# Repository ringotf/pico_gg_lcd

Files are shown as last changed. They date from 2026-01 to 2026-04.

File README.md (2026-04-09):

# Pico GG LCD

Work-in-progress update to Trirosmos' original RP2040 Game Gear mod.

More details on the [SMSPower Forum Thread](https://www.smspower.org/forums/20164-OpenSourceGameGearScreenReplacementPicoGGLCD)

## Project Status

Alpha. Main features have been proof-of-concepted, and a working prototype built based on the WL355608 branch (with minimal bodge-fixes). 
The firmware supports both Game Gear and Master System mode, but no adjustable scaling options yet.

> [!NOTE]
> **The PCB design is likely to see major changes.** The current build includes unneccessary placeholder components to be removed, amongst other things. The [WL355608-Dev](tree/WL355608_dev) branch will be updated with Beta changes first.

## "Working" Features

- 640x480 "HD" 3.5inch LCD WL-355608
- HDMI video output with stereo audio using [ikjordan PicoDVI branch](https://github.com/ikjordan/picodvi)
- LED Brightness control with Brightness Wheel
- On-Screen menu. For menu items. And other things.
- GG Mode at 4x horizontal, 3x vertical scaling
- SMS mode at 2x scaling
- [Installation Ribbon](#installation-ribbon)
- 3d printable screen holder

### Demo Video Link (Quiet/NoAudio):

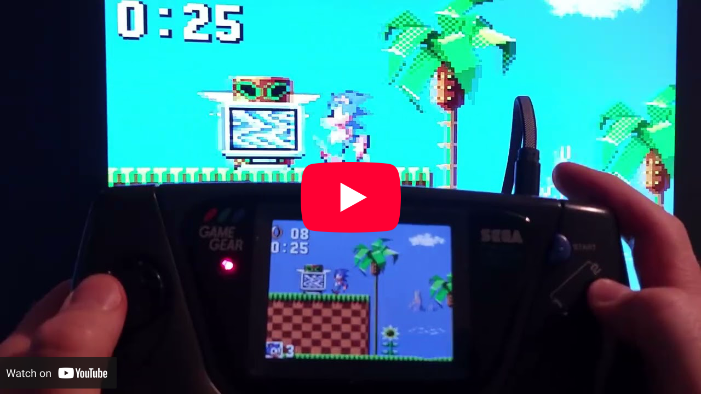
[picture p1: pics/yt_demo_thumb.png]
[](https://www.youtube.com/watch?v=du8Fr7flVrw)

### Another with better audio:

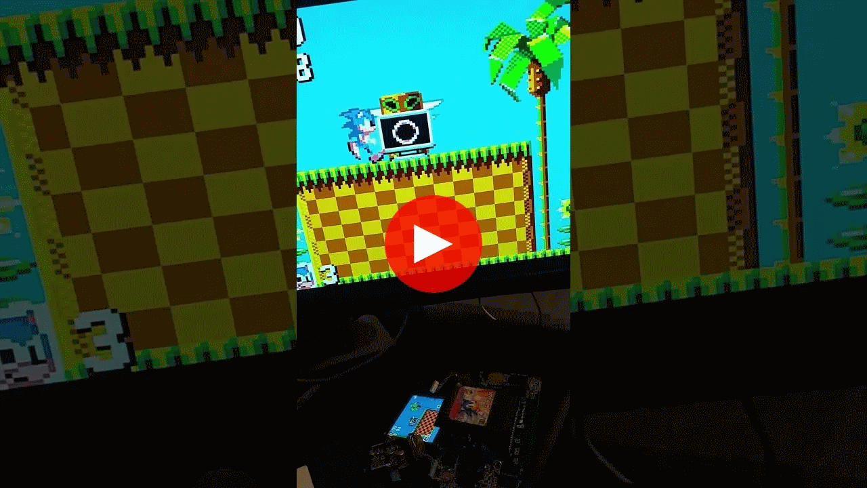
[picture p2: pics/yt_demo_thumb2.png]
[](https://www.youtube.com/watch?v=f37Q6rag2ZQ)

### PCB (Alpha Prototype 4)

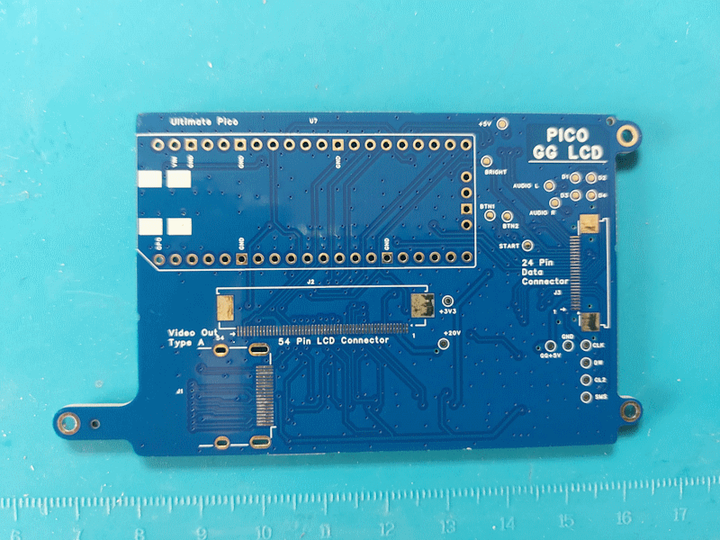
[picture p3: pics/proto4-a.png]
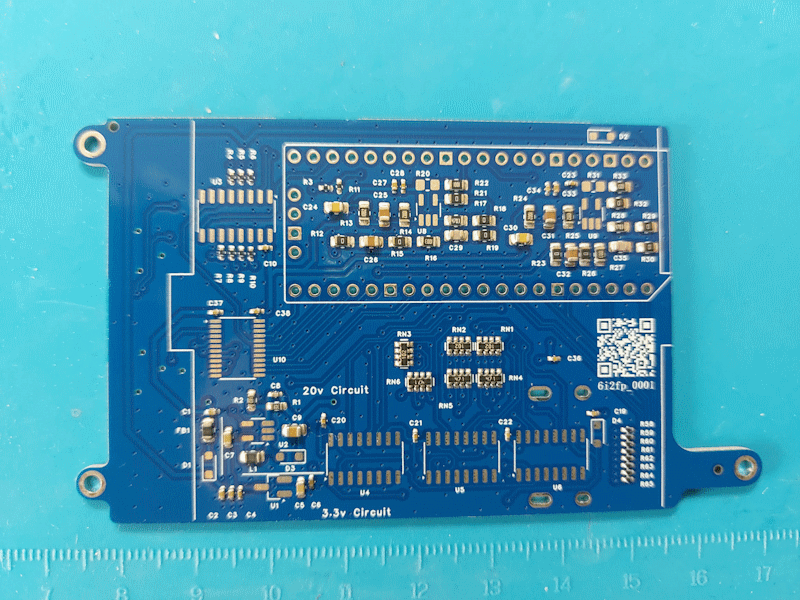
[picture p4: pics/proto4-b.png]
 

## Issues/Upcoming Changes/ToDo

- The LCD connector ribbon is likely to be rotated 180 degrees, will make soldering easier for both LCD and HDMI connectors.
- The op-amps used for audio capture will probably be changed for a dual-op-amp instead of two singles.
- Audio has lots of interference, could be from the LCD mod, could be from the GG.
- The XC6206 3.3v regulator was used to try and eliminate noise from the Pico's onboard regulator interferring with ADC, but might be unneccessary now.
- Remove placeholder components in the audio circuit.
- Corrected LED backlight dimming circuit - currently uses 2 GPIO pins, plus a bodge as shown below.
- The GG Clock pin is no longer needed.
- HDMI Hot-Plug-Detect implemented with the spare Pico GPIO pin.
- Installation Ribbon needs updating to remove the GG Clock pin. 
- Memory. Firmware currently uses 2 framebuffers to help prevent tearing, but with all the other features the Pico is starting to stretch its 264KB RAM... rotating the LCD connector so the LCD is mounted up-right might help allow a single framebuffer and recover some memory for other features.
- The shift registers probably have more performance in them, might be able to work with 2 instead of 3 - might not be worth finding out?

### RP2040 vs RP2350B

Instead of using serial->parallel shift registers to implement the LCD RGB444 input, we could use the extra pins of the Pico2 48-GPIO RP2350B. These are more expensive even after excluding the cost of the 3x 74HC595 shift registers needed for the RP2040, but would simplify the PCB a lot... It was fun to make the project work on an RP2040!

Plus the extra ram of the RP2350 (520KB vs 264KB) will help allow other features to be added to the firmware.

## How It Works

The Game Gear outputs serial RGB444, which is captured using PIO programs and stored in a 16-Bit framebuffer. 
- GG video capture uses 7 GPIO pins: 4 data + 3 control. (*6 without GG Clock now, but anyway)
- PicoDVI output uses 8 GPIO pins.
- LED Backlight brightness control uses 2 GPIO pins.
- LCD requires 3 control signals, Reset, Clock and Data-Enable.

This is 20 pins for capture, HDMI output and LCD control, leaving **10** pins from the 30 GPIO Ultimate Pico.

The LCD expects parallel RGB for 640x480 60Hz. For RGB444 the lcd needs **12** input lines.

To feed the LCD with 12 data inputs, we can use serial-to-parallel shift registers to read data from the Pico serially over a few pins, and send to the LCD over 12 parallel pins.

Although the shift registers have their own timing limits, by using a combination of multiple registers and reusing the same data (scale the image horizontally by clocking the LCD up to 4 times) we can reduce the load on the individual register.

The outputs from the shift registers are interleaved to the LCD to avoid requiring any bit-shifting from the frame buffer.

So the Pico outputs 160 pixels of 12 bit data, with 4 bits per shift register clock to 3 shift registers, and then clocks the LCD 4x for an effective 640 pixels.
Using 5 GPIO pins: 3 MOSI, 1 shift register Latch, 1 shift register clock.

Which leaves a few GPIO pins for audio capture!

### Shift Register Diagram

Hopefully this diagram helps visually explain how the shift registers are wired in:

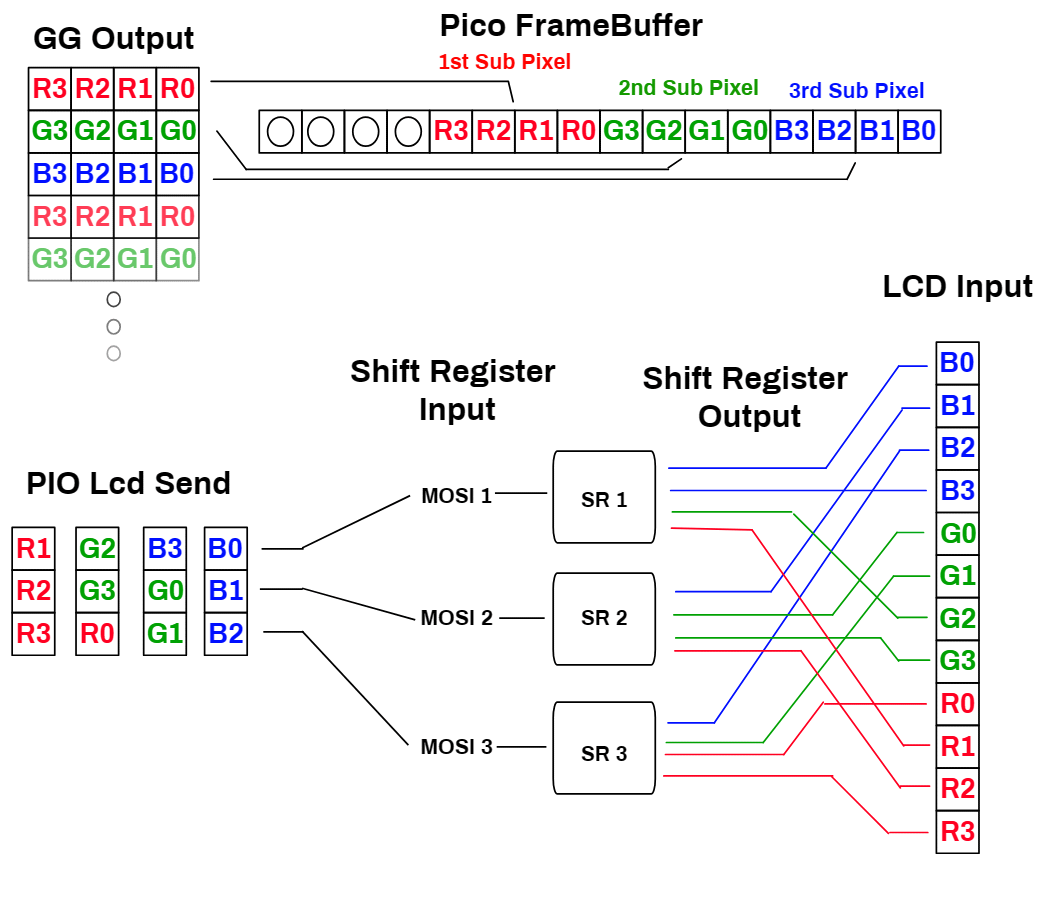
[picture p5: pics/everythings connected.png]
Yes
 

## Build Pics (Including backlight bodge)

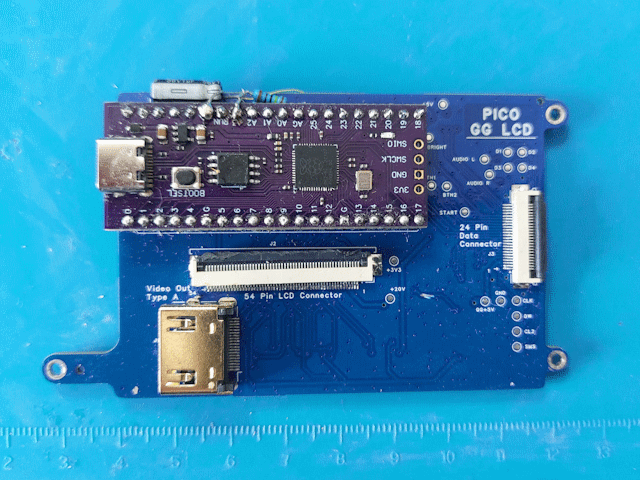
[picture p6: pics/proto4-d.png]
 
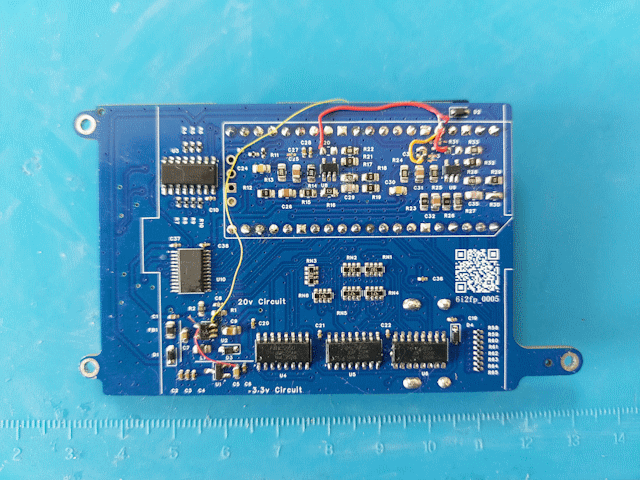
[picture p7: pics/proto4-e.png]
 
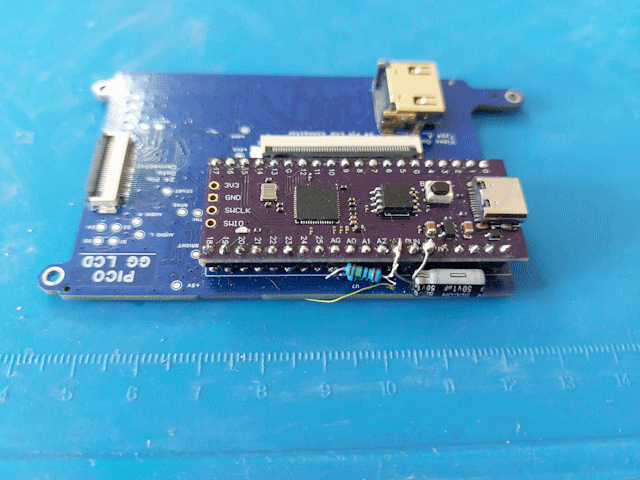
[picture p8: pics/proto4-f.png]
PCB Bodge


### Assembled PCB Test

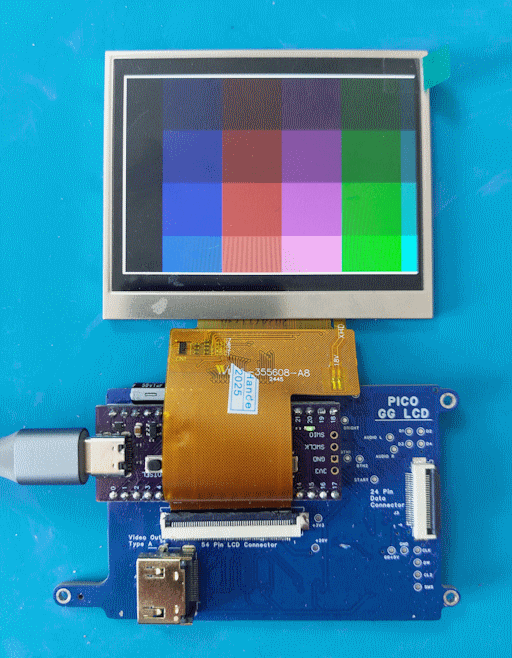
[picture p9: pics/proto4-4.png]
Assembled PCB Test


### Main Board Installed

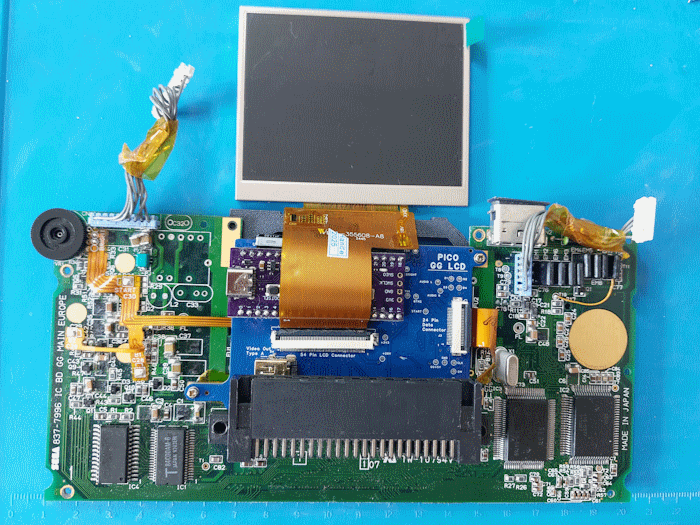
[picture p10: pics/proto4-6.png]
Main Board Installed


### Main Board Testing

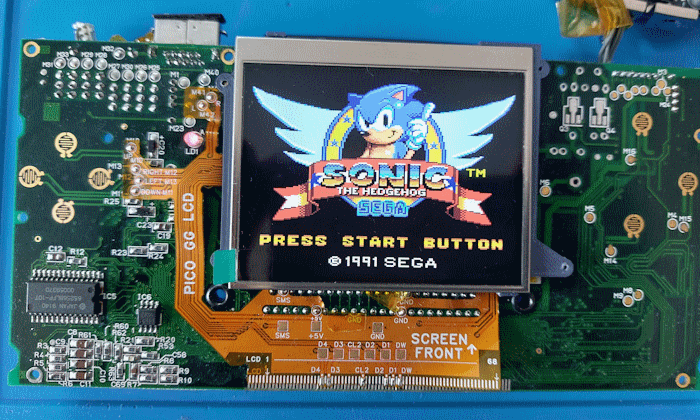
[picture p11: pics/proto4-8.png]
Main Board Testing


### Awaiting Closure

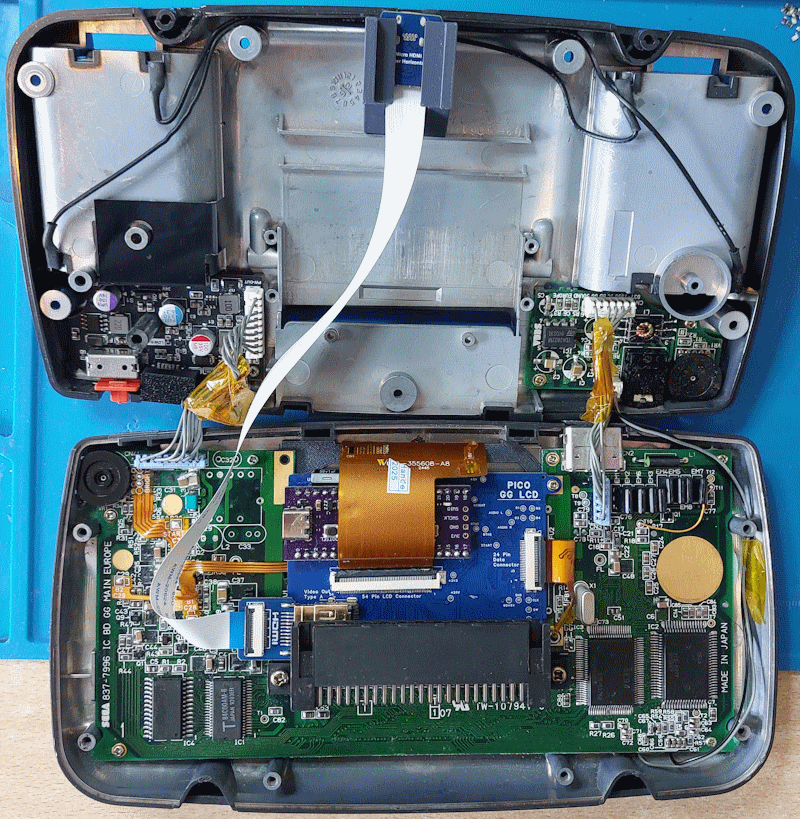
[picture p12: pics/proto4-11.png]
Awaiting Closure


### Completed Build

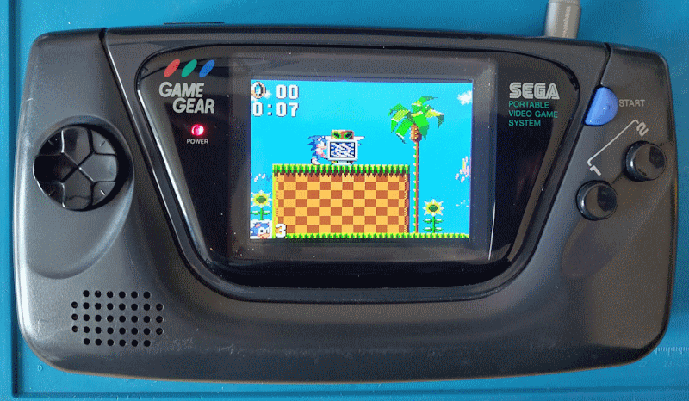
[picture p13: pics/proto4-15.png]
Completed Build


## Installation Ribbon

There is an FPC Installation Ribbon project for easy soldering to the game gear main board. This is designed for the arms to be folded out to reach the various solder points.

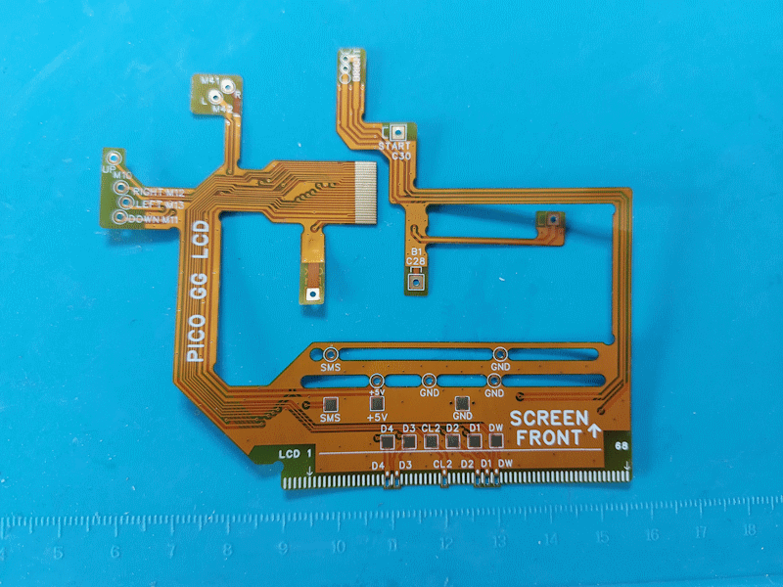
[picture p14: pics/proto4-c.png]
Installation Ribbon


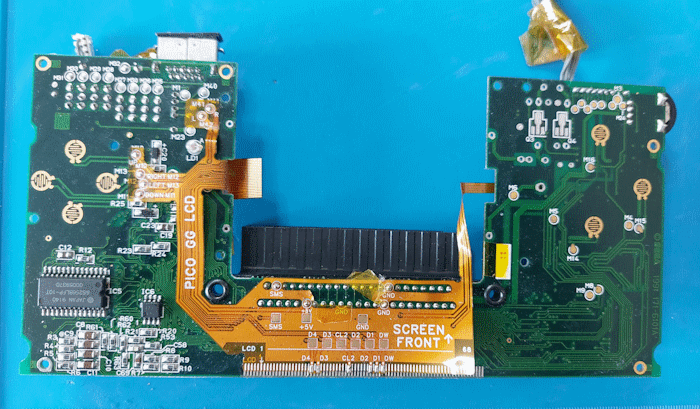
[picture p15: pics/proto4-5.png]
Installed Ribbon Front


## Schematic

Schematic PDF: [hw/GG_LCD_DIY.pdf](hw/GG_LCD_DIY.pdf)

## Gerbers/Bom

Main PCB Gerbers & Bom: [hw\jlcpcb\production_files](hw\jlcpcb\production_files)

Installation Ribbon Gerbers & Bom: [hw\InstallationRibbon\jlcpcb\production_files](hw\InstallationRibbon\jlcpcb\production_files)

Full details in the above files and KiCad project, but here's some of the highlights:

| Component | Description | Quantity |  Example Link(s) | 
| --- | --- | --- | --- |
| Pico GG LCD PCB | Printed Circuit Board | x1 |  |
| WL-355608 | 640x480 3.5" LCD<br />(Also sold as "RG35XX Replacement Screen") | x1 | https://www.aliexpress.com/item/1005005669918579.html <br /> https://www.aliexpress.com/item/1005007035513918.html |
| 30-GPIO Ultimate Pico | Purple RP2040 | x1 | https://www.aliexpress.com/item/1005005594351599.html <br /> https://www.aliexpress.com/item/1005007057526637.html |
| 54-Pin FPC Connector | LCD Ribbon Connector - Flip/Drawer "Bottom" | x1 | https://www.aliexpress.com/item/1005006818638048.html <br /> https://www.aliexpress.com/item/1005008569249941.html |
| 24-Pin FPC Connector | Data Connector - Flip/Drawer "Bottom" | x1 | https://www.aliexpress.com/item/1005006818638048.html <br /> https://www.aliexpress.com/item/1005008569249941.html |
| XC6206P332MR-G | 3.3v Regulator | x1 | https://www.aliexpress.com/item/33025330295.html |
| TPS61040DBVR | 20v Regulator | x1 | https://www.aliexpress.com/item/1005007852981529.html |
| [74HC595D](docs/sn74hc595.pdf) | Serial->Parallel Shift Registers | x3 | https://www.aliexpress.com/item/1005009410525894.html |
| [74HC165D](docs/sn74hc165.pdf) | Parallel->Serial Shift Register | x1 | https://www.aliexpress.com/item/1005009410525894.html |
| [SN74LVC4245APWR](docs/sn74lvc4245a.pdf) | Level-Shifting Transceiver | x1 | https://www.aliexpress.com/item/1005009206069625.html <br /> https://www.aliexpress.com/item/1005011552818805.html |
| [LMV321IDBVR](docs/lmv321.pdf) | Single Op-Amp | x2 | https://www.aliexpress.com/item/1005006127706764.html |
| HDMI Connector |  | x1 Optional | https://www.aliexpress.com/item/1005001412266648.html |
| DIY HDMI Connector | (See note below) | x2 Optional | https://www.aliexpress.com/item/1005004318851140.html <br /> https://www.aliexpress.com/item/1005006437300837.html |
| 20pin 0.5mm FFC | Flat cable for HDMI connectors<br />(Cheap but unshielded) | x1 Optional | https://www.aliexpress.com/item/1005007561337665.html |

Plus inductor, ferrite bead, diodes, capacitors, resistors, resistor network/arrays.

### DIY HDMI Cable Note

> [!WARNING]
> For DIY HDMI Cable, you need to buy **both Male and Female connector ends from the same listing** to ensure compatability with each other. 

Multiple listings included just as examples. If you mix-and-match across listings you might find the connector boards have different pinouts.

The cable requires a Type-A1 Male connector (the standard type) to connect to the PCB, plus a Female receptacle connector to be mounted inside the case, such as the Standard Type-A (often A4), or Micro-HDMI (often D4), or Mini-HDMI (Often C4) plus a 20cm FFC ribbon to join them together. (15cm is probably ok too)

The Micro-HDMI female connector is ideal for the minimising the size of the hole in the case, but still requires an appropriate Micro-HDMI cable or adapter to connect to a TV.

### DIY HDMI Examples 
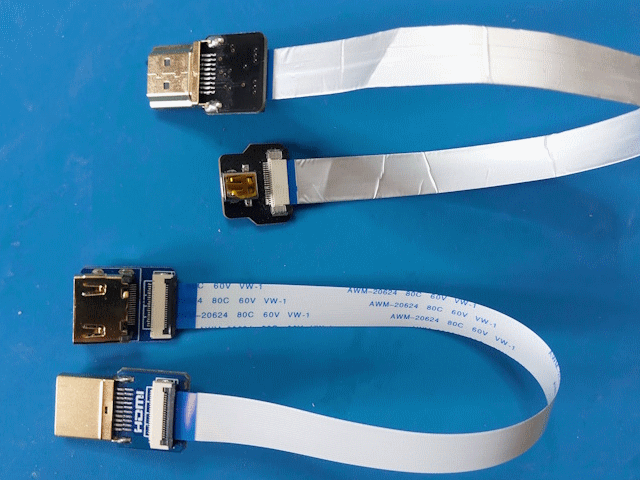
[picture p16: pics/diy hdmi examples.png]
diy hdmi examples


### Micro-HDMI Shell Hole

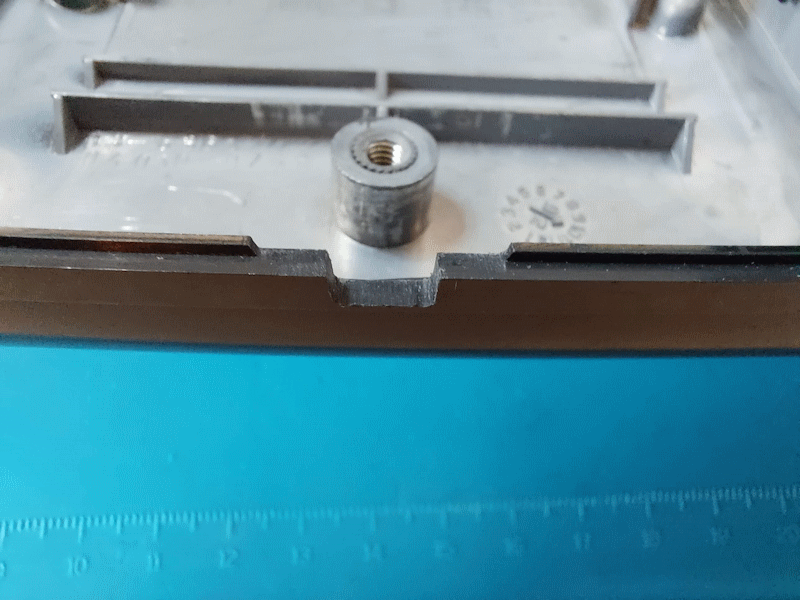
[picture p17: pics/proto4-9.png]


### Micro-HDMI Connector Mounted

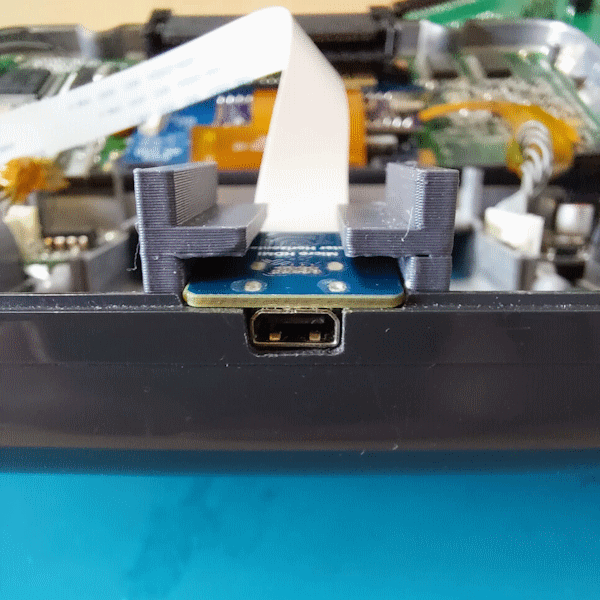
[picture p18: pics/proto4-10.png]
Micro-HDMI Connector Mounted


### Complete Micro-HDMI Install

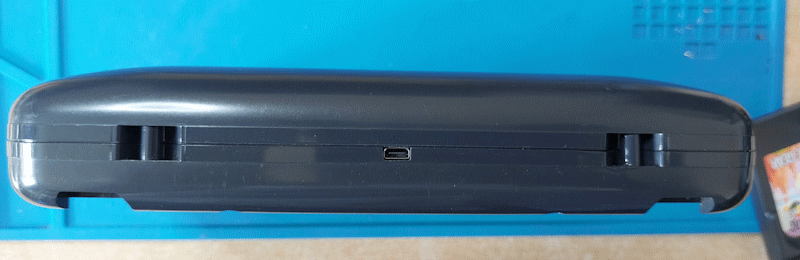
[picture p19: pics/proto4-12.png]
Completed Micro-HDMI Install


### Don't Do This! Careful how the ribbon folds within the case!

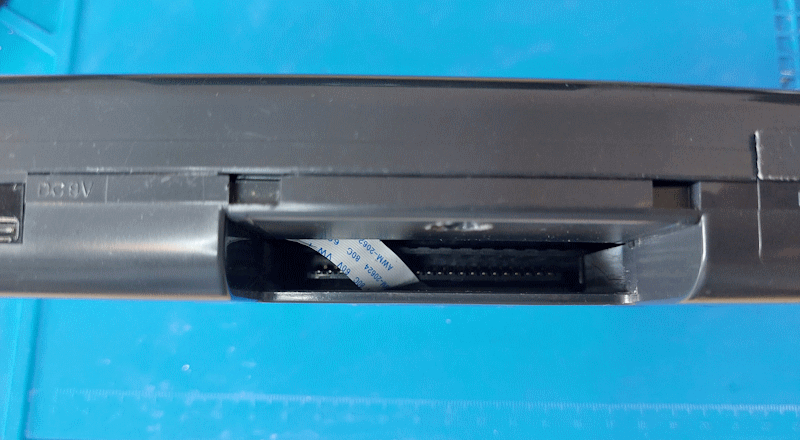
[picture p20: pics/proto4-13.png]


# <br/><br/><br/>
### Original project readme for reference. This branch builds upon the fundamentals below:
<br/><br/>
# Pico GG LCD

install_image

RP2040-based Game Gear screen replacement kit.
Even a cheapo modern LCD has much, much, much better contrast ratio than the OG screen.

## Building the software

Clone this repository and pull all submodules:
```Bash
git clone https://github.com/Trirosmos/pico_gg_lcd
cd pico_gg_lcd
git submodule update --init --recursive
```

Then, run `sw/build.sh`:

```Bash
cd sw
mkdir build
cd build
cmake ../CMakeLists.txt
make
```

This should generate an uf2 file you can upload to the RP2040;

## Building the hardware

Componentes you'll need and their approximate cost:

- Pico GG LCD PCB ($5)
- [PMOD HDMI adapter board](https://aliexpress.com/w/wholesale-pmod%2525252dhdmi.html?spm=a2g0o.detail.search.0) ($4) 
- [54-pin FPC connector adapter board](https://aliexpress.com/item/32827105259.html) ($2)
- [LQ035NC111 LCD module](https://aliexpress.com/w/wholesale-LQ035NC111.html?spm=a2g0o.home.search.0) ($10)
- [RP2040 board that exposes all 30 GPIOs](https://aliexpress.com/item/1005003796653297.html) ($4)
- BS170 or similar NMOSFET ($0.3)
- ~470uH axial THT inductor ($0.2)
- 2x SOD-123 Schottky diode ($0.4)
- 10k 0805 resistor ($0.05)
- 100k 0805 resistor ($0.05)
- 100nF 0805 resistor ($0.05)
- 100uF 0805 resistor ($0.05)
- 22uF 0805 resistor ($0.05)

Total approximate BOM cost: $26

First assemble passive components and transistor, then the RP2040 board and leave the FPC connector to be connected last.
The final board should look something like this, sans the bodge wire:

board_assembly

## How Game Gear video signals work

The Game Gear ASIC generates digital video signals that the LCD drivers in the LCD ribbon use to drive the actual display segments.

In NTSC mode, i.e, when test pad T10 is connected to +5V, the timings of the signals from the ASIC closely resemble what one would expect from a console like the Master System. All screen replacement kits run the Game Gear in this mode, as far as I'm aware. 

The communication protocol used between the ASIC and the LCD drivers in this mode is [well documented](https://www.retrosix.wiki/va0va1-lcd-interface-game-gear) and essentially boils down to:

- 32 MHz pixel clock (same as the main system clock)
- 4 bit data bus carrying one channel of color data at a time
- VSync signal
- HSync signal

## How the RP2040 captures GG video

One of the PIOs is takes alongside three DMA channels with building a live framebuffer in RAM with the image data the GG is sending out.

Three PIO SMs are used in the following manner:

- SM0 detects when a frame starts and triggers an IRQ.
- SM1 detects the IRQ from SM0 and starts detecting HSync pulses. It triggers an IRQ when it does.
- SM2 detects the IRQ from SM1 and proceeds to capture pixel data and push it out to the RX FIFO.

One of the DMA channels then takes the 12bpp pixel data from the PIO RX FIFO and saves it into RAM.

Finally, one of the CPU cores upscales the image and sends it out to the LCD.

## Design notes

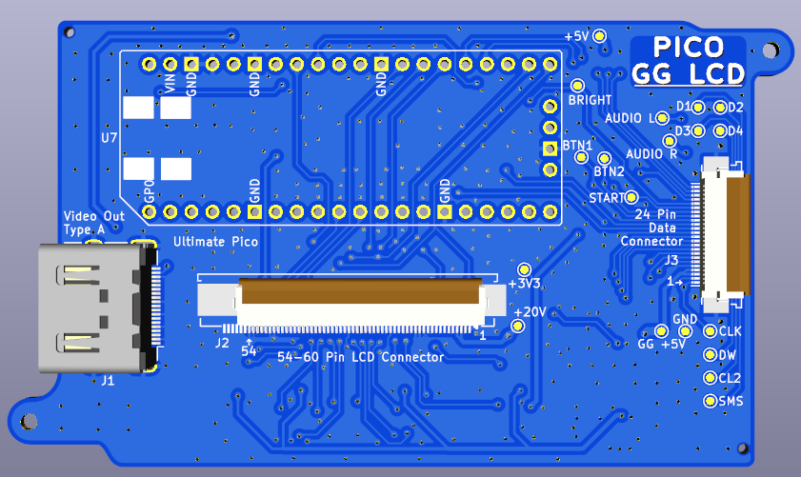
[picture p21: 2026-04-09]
pics/proto3-1.png

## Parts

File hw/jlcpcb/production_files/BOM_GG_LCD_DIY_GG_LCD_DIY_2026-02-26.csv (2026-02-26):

No. | Quantity | Comment | Designator | Footprint | Value | Manufacturer Part | Manufacturer | Supplier Part | Supplier | Name
1 | 5 | 10uF | C1,C2,C3,C27,C33 | gg_lcd:C_0402_1005Metric_Pad0.74x0.62mm_HandSolder | 10uF | CL05A106MQ5NUNC | SAMSUNG(三星) | C15525 | LCSC | 10uF
2 | 12 | 100nF | C4,C10,C19,C20,C21,C22,C23,C28,C34,C36,C37,C38 | gg_lcd:C_0402_1005Metric_Pad0.74x0.62mm_HandSolder | 100nF | CL05B104KO5NNNC | SAMSUNG(三星) | C1525 | LCSC | 100nF
3 | 2 | 22uF | C5,C7 | Capacitor_SMD:C_0603_1608Metric_Pad1.08x0.95mm_HandSolder | 22uF | CL10A226MQ8NRNC | SAMSUNG(三星) | C59461 | LCSC | 22uF
4 | 1 | 1uF | C6 | gg_lcd:C_0402_1005Metric_Pad0.74x0.62mm_HandSolder | 1uF | CL05A105KA5NQNC | SAMSUNG(三星) | C52923 | LCSC | 1uF
5 | 1 | 22pF | C8 | gg_lcd:C_0402_1005Metric_Pad0.74x0.62mm_HandSolder | 22pF | 0402CG220J500NT | FH(风华) | C1555 | LCSC | 22pF
6 | 1 | 22uF | C9 | Capacitor_SMD:C_0805_2012Metric_Pad1.18x1.45mm_HandSolder | 22uF | CL21A226MAQNNNE | SAMSUNG(三星) | C45783 | LCSC | 22uF
7 | 2 | 100nF | C24,C30 | Capacitor_SMD:C_0805_2012Metric_Pad1.18x1.45mm_HandSolder | 100nF | CL21B104KCFNNNE | SAMSUNG(三星) | C28233 | LCSC | 100nF
8 | 4 | 10uF | C25,C26,C31,C32 | Capacitor_SMD:C_0805_2012Metric_Pad1.18x1.45mm_HandSolder | 10uF | CL21A106KAYNNNE | SAMSUNG(三星) | C15850 | LCSC | 10uF
9 | 2 | 22pF | C29,C35 | Capacitor_SMD:C_0805_2012Metric_Pad1.18x1.45mm_HandSolder | 22pF | CL21C220JBANNNC | SAMSUNG(三星) | C1804 | LCSC | 22pF
10 | 3 | B0540WS | D1,D3,D4 | Diode_SMD:D_SOD-323_HandSoldering |  | B0540WS | R+O(宏嘉诚) | C7420326 | LCSC | B0540WS
11 | 1 | B0540WS | D2 | Diode_SMD:D_SOD-323_HandSoldering | B0540WS | B0540WS | R+O(宏嘉诚) | C7420326 | LCSC | B0540WS
12 | 1 | GZ2012D601TF | FB1 | Inductor_SMD:L_0805_2012Metric_Pad1.15x1.40mm_HandSolder | GZ2012D601TF | GZ2012D601TF | Sunlord(顺络) | C1017 | LCSC | GZ2012D601TF
13 | 2 | MountingHole_Pad | H1,H2 | MountingHole:MountingHole_2.2mm_M2_ISO7380_Pad |  |  |  |  |  | MountingHole_Pad
14 | 1 | MountingHole_Pad | H3 | MountingHole:MountingHole_2.2mm_M2_ISO7380_Pad | MountingHole_Pad |  |  |  |  | MountingHole_Pad
15 | 1 | Micro \\"Video Out\\" Type A | J1 | gg_lcd:HDMI_A_Molex_208658-1001_Horizontal | Micro \\"Video Out\\" Type A |  |  |  |  | Micro \\"Video Out\\" Type A
16 | 1 | Conn_01x54 | J2 | gg_lcd:1x54 FPC Connector 0.5mm HandSolder | Conn_01x54 |  |  |  |  | Conn_01x54
17 | 1 | 01x24 Conn | J3 | gg_lcd:Jushuo_AFC07-S24FCA-00_1x24-1MP_P0.50_Horizontal | 01x24 Conn |  |  |  |  | 01x24 Conn
18 | 1 | 10uH | L1 | Inductor_SMD:L_0805_2012Metric_Pad1.15x1.40mm_HandSolder | 10uH | SDFL2012S100KTF | Sunlord(顺络) | C1046 | LCSC | 10uH
19 | 1 | gg_lcd:lcd_template_with_ribbon | LCD1 | gg_lcd:lcd_template_with_ribbon
20 | 1 | MountingHole | MHP1 | MountingHole:ToolingHole_1.152mm |  |  |  |  |  | MountingHole
21 | 1 | MountingHole | MHP2 | MountingHole:ToolingHole_1.152mm | MountingHole |  |  |  |  | MountingHole
22 | 1 | 2MΩ | R1 | Resistor_SMD:R_0603_1608Metric_Pad0.98x0.95mm_HandSolder | 2MΩ | 0603WAF2004T5E | UNI-ROYAL(厚声) | C22976 | LCSC | 2MΩ
23 | 1 | 150kΩ | R2 | Resistor_SMD:R_0603_1608Metric_Pad0.98x0.95mm_HandSolder | 150kΩ | 0603WAF1503T5E | UNI-ROYAL(厚声) | C22807 | LCSC | 150kΩ
24 | 1 | 1kΩ | R3 | gg_lcd:R_0402_1005Metric_Pad0.72x0.64mm_HandSolder | 1kΩ | 0402WGF1001TCE | UNI-ROYAL(厚声) | C11702 | LCSC | 1kΩ
25 | 7 | 100Ω | R4,R5,R6,R7,R8,R9,R10 | gg_lcd:R_0402_1005Metric_Pad0.72x0.64mm_HandSolder | 100Ω | 0402WGF1000TCE | UNI-ROYAL(厚声) | C25076 | LCSC | 100Ω
26 | 1 | 2kΩ | R11 | gg_lcd:R_0402_1005Metric_Pad0.72x0.64mm_HandSolder | 2kΩ | 0402WGF2001TCE | UNI-ROYAL(厚声) | C4109 | LCSC | 2kΩ
27 | 10 | 0Ω | R12,R15,R18,R19,R21,R23,R26,R29,R30,R32 | Resistor_SMD:R_0805_2012Metric_Pad1.20x1.40mm_HandSolder | 0Ω | 0805W8F0000T5E | UNI-ROYAL(厚声) | C17477 | LCSC | 0Ω
28 | 4 | 10kΩ | R13,R14,R24,R25 | Resistor_SMD:R_0805_2012Metric_Pad1.20x1.40mm_HandSolder | 10kΩ | 0805W8F1002T5E | UNI-ROYAL(厚声) | C17414 | LCSC | 10kΩ
29 | 2 | 100kΩ | R16,R27 | Resistor_SMD:R_0805_2012Metric_Pad1.20x1.40mm_HandSolder | 100kΩ | 0805W8F1003T5E | UNI-ROYAL(厚声) | C149504 | LCSC | 100kΩ
30 | 2 | 470kΩ | R17,R28 | Resistor_SMD:R_0805_2012Metric_Pad1.20x1.40mm_HandSolder | 470kΩ | 0805W8F4703T5E | UNI-ROYAL(厚声) | C17709 | LCSC | 470kΩ
31 | 2 | XR | R20,R31 | Resistor_SMD:R_0805_2012Metric_Pad1.20x1.40mm_HandSolder |  |  |  |  |  | XR
32 | 2 | 1kΩ | R22,R33 | Resistor_SMD:R_0805_2012Metric_Pad1.20x1.40mm_HandSolder | 1kΩ | 0805W8F1001T5E | UNI-ROYAL(厚声) | C17513 | LCSC | 1kΩ
33 | 8 | 220Ω | R58,R59,R60,R61,R62,R63,R64,R65 | gg_lcd:R_0402_1005Metric_Pad0.72x0.64mm_HandSolder | 220Ω | 0402WGF2200TCE | UNI-ROYAL(厚声) | C25091 | LCSC | 220Ω
34 | 3 | 1kΩ | RN1,RN2,RN3 | gg_lcd:R_Array_Convex_4x0603 | 1kΩ | 4D03WGJ0102T5E | UNI-ROYAL(厚声) | C20197 | LCSC | 1kΩ
35 | 3 | 470Ω | RN4,RN5,RN6 | gg_lcd:R_Array_Convex_4x0603 | 470Ω | 4D03WGJ0471T5E | UNI-ROYAL(厚声) | C25510 | LCSC | 470Ω
36 | 1 | GG+5V | T1 | gg_lcd:TestPoint_Pad_D1.0mm |  |  |  |  |  | GG+5V
37 | 1 | GND | T2 | gg_lcd:TestPoint_Pad_D1.0mm |  |  |  |  |  | GND
38 | 1 | BRIGHT | T3 | gg_lcd:TestPoint_Pad_D1.0mm |  |  |  |  |  | BRIGHT
39 | 1 | START | T4 | gg_lcd:TestPoint_Pad_D1.0mm |  |  |  |  |  | START
40 | 1 | BTN2 | T5 | gg_lcd:TestPoint_Pad_D1.0mm |  |  |  |  |  | BTN2
41 | 1 | BTN1 | T6 | gg_lcd:TestPoint_Pad_D1.0mm |  |  |  |  |  | BTN1
42 | 1 | AUDIO L | T11 | gg_lcd:TestPoint_Pad_D1.0mm |  |  |  |  |  | AUDIO L
43 | 1 | AUDIO R | T12 | gg_lcd:TestPoint_Pad_D1.0mm |  |  |  |  |  | AUDIO R
44 | 1 | CLK | T13 | gg_lcd:TestPoint_Pad_D1.0mm |  |  |  |  |  | CLK
45 | 1 | SMS | T14 | gg_lcd:TestPoint_Pad_D1.0mm | SMS |  |  |  |  | SMS
46 | 1 | DW | T15 | gg_lcd:TestPoint_Pad_D1.0mm |  |  |  |  |  | DW
47 | 1 | CL2 | T16 | gg_lcd:TestPoint_Pad_D1.0mm |  |  |  |  |  | CL2
48 | 1 | D4 | T17 | gg_lcd:TestPoint_Pad_D1.0mm |  |  |  |  |  | D4
49 | 1 | D3 | T18 | gg_lcd:TestPoint_Pad_D1.0mm |  |  |  |  |  | D3
50 | 1 | D2 | T19 | gg_lcd:TestPoint_Pad_D1.0mm |  |  |  |  |  | D2
51 | 1 | D1 | T20 | gg_lcd:TestPoint_Pad_D1.0mm |  |  |  |  |  | D1
52 | 1 | +3V3 | TP15 | gg_lcd:TestPoint_Pad_D1.0mm |  |  |  |  |  | +3V3
53 | 1 | +20V | TP16 | gg_lcd:TestPoint_Pad_D1.0mm |  |  |  |  |  | +20V
54 | 1 | +5V | TP17 | gg_lcd:TestPoint_Pad_D1.0mm |  |  |  |  |  | +5V
55 | 1 | XC6206P332MR-G | U1 | Package_TO_SOT_SMD:SOT-23_Handsoldering | XC6206P332MR-G | XC6206P332MR-G | TOREX(特瑞仕) | C5446 | LCSC | XC6206P332MR-G
56 | 1 | TPS61040DBVR | U2 | Package_TO_SOT_SMD:SOT-23-5_HandSoldering |  | TPS61040DBVR | TI(德州仪器) | C7722 | LCSC | TPS61040DBVR
57 | 1 | 74HC165D,653 | U3 | Package_SO:SO-16_3.9x9.9mm_P1.27mm |  | 74HC165D,653 | Nexperia(安世) | C5613 | LCSC | 74HC165D,653
58 | 2 | 74HC595D,118 | U4,U5 | Package_SO:SO-16_3.9x9.9mm_P1.27mm |  | 74HC595D,118 | Nexperia(安世) | C5947 | LCSC | 74HC595D,118
59 | 1 | 74HC595D,118 | U6 | Package_SO:SO-16_3.9x9.9mm_P1.27mm | 74HC595 | 74HC595D,118 | Nexperia(安世) | C5947 | LCSC | 74HC595D,118
60 | 1 | Utimate Pico | U7 | gg_lcd:RPi_Pico_SMD_TH_NoPads | Utimate Pico |  |  |  |  | Utimate Pico
61 | 1 | LMV321IDBVR | U8 | Package_TO_SOT_SMD:SOT-23-5_HandSoldering | TPS61040DBV | LMV321IDBVR | TI(德州仪器) | C7972 | LCSC | LMV321IDBVR
62 | 1 | LMV321IDBVR | U9 | Package_TO_SOT_SMD:SOT-23-5_HandSoldering |  | LMV321IDBVR | TI(德州仪器) | C7972 | LCSC | LMV321IDBVR
63 | 1 | SN74LVC4245APWR | U10 | gg_lcd:TSSOP-24_4.4x7.8mm_P0.65mm | SN74LVC4245APWR | SN74LVC4245APWR | TI(德州仪器) | C7859 | LCSC | SN74LVC4245APWR

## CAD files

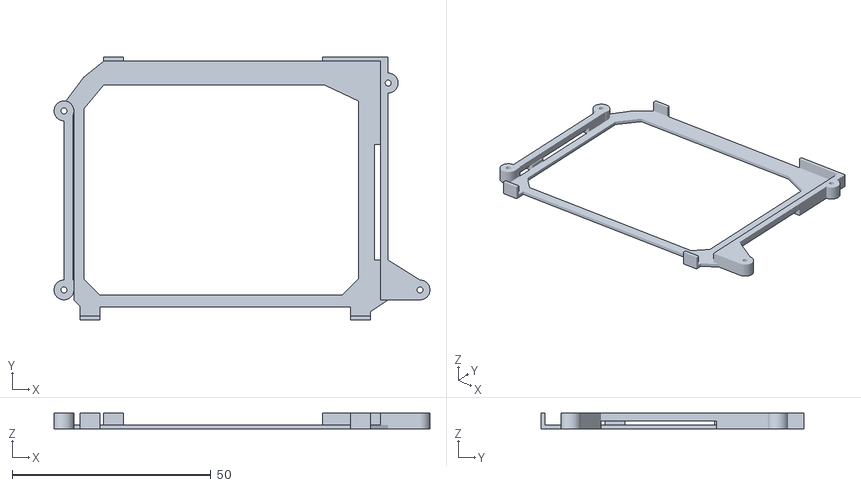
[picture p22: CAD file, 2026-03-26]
3dprints/PICO GG LCD FRAME 2.stl
94.5 x 66.0 x 4.00

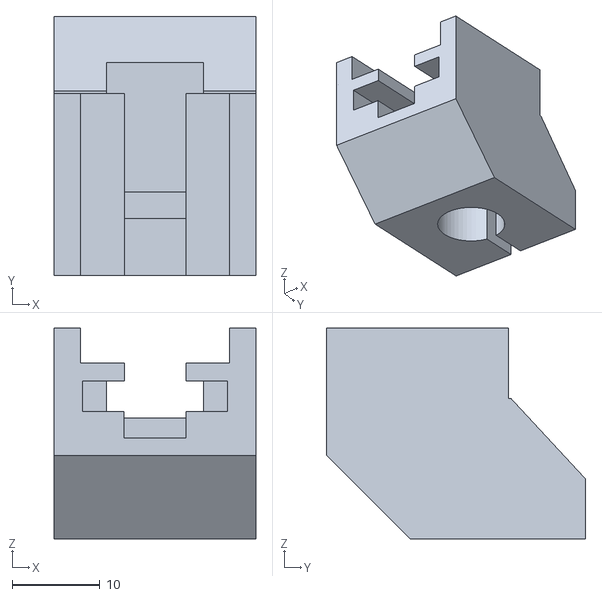
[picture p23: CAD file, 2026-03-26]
3dprints/PICO GG MICRO NOT HDMI UPSIDEDOWN 2.stl
23.0 x 29.5 x 24.0

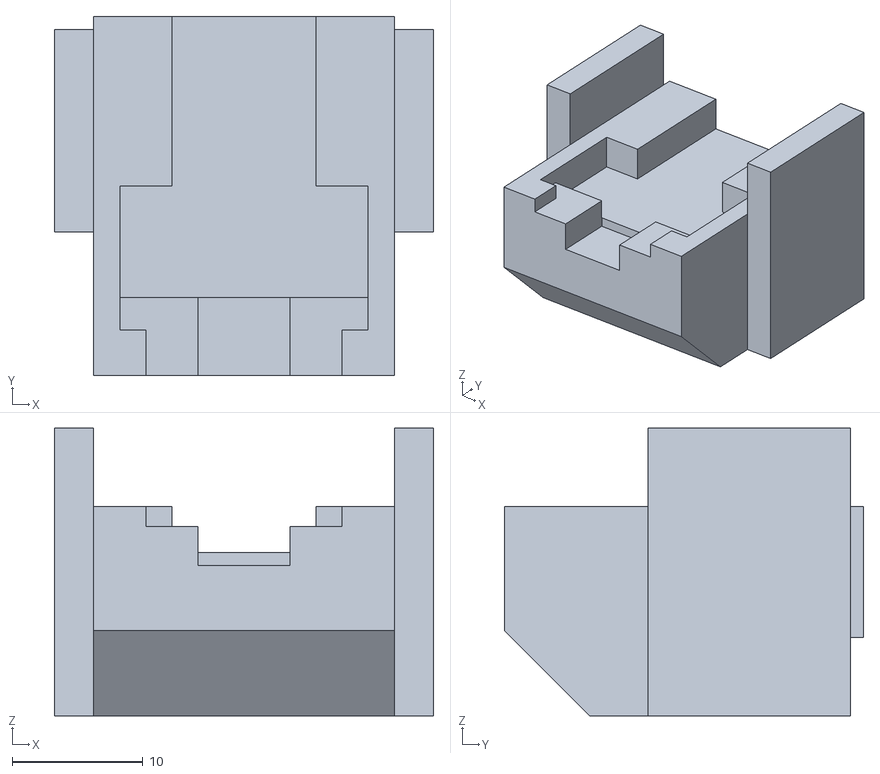
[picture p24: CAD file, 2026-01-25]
3dprints/PICO GG MICRO NOT HDMI UPSIDEDOWN.stl
29.0 x 27.5 x 22.0

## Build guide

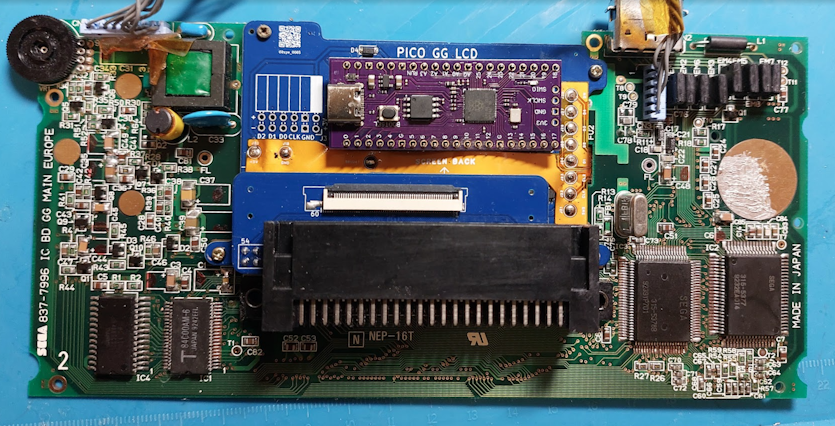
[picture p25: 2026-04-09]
pics/build1d.png

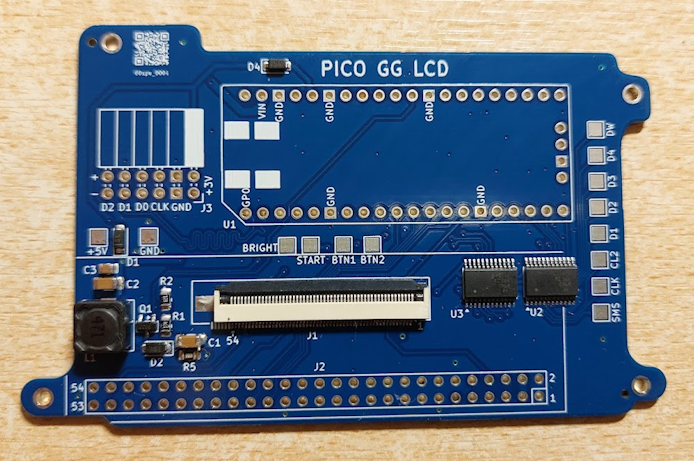
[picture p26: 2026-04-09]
pics/build1e.png

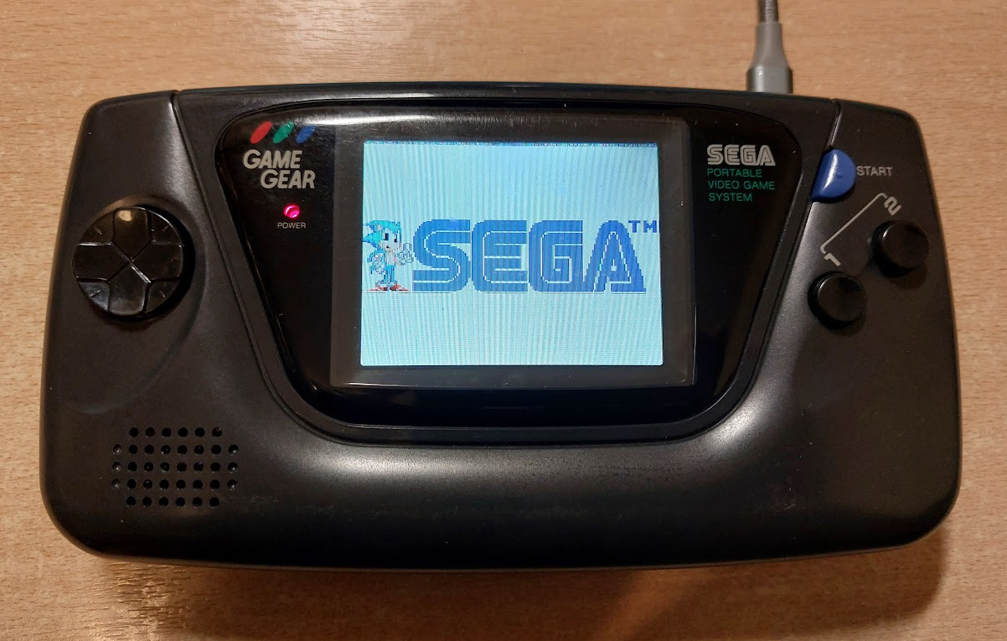
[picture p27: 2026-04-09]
pics/build1a.png

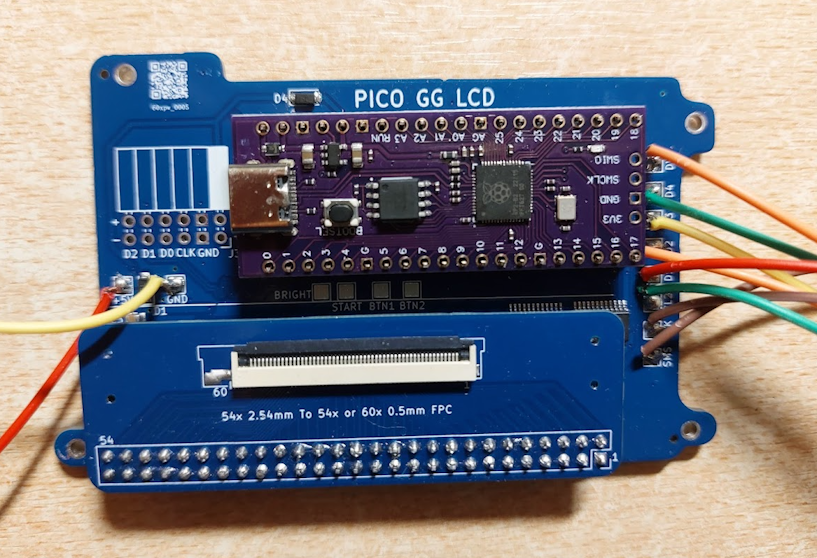
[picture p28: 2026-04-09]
pics/build1f.png

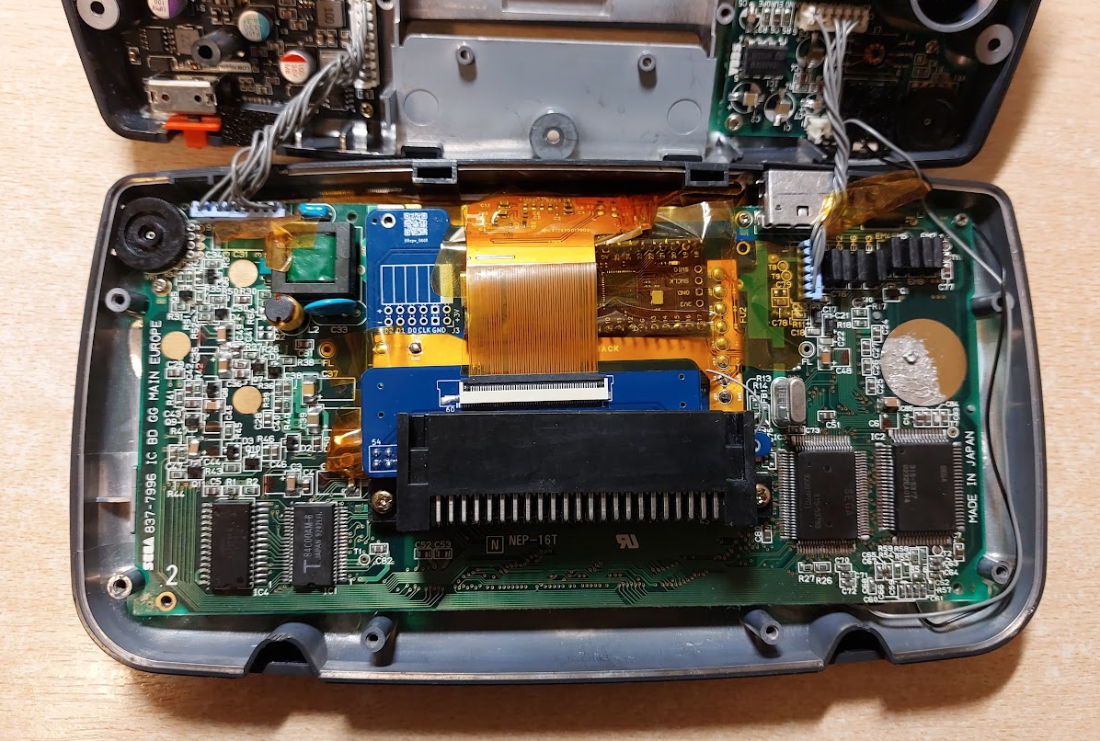
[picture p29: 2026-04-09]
pics/build1b.png

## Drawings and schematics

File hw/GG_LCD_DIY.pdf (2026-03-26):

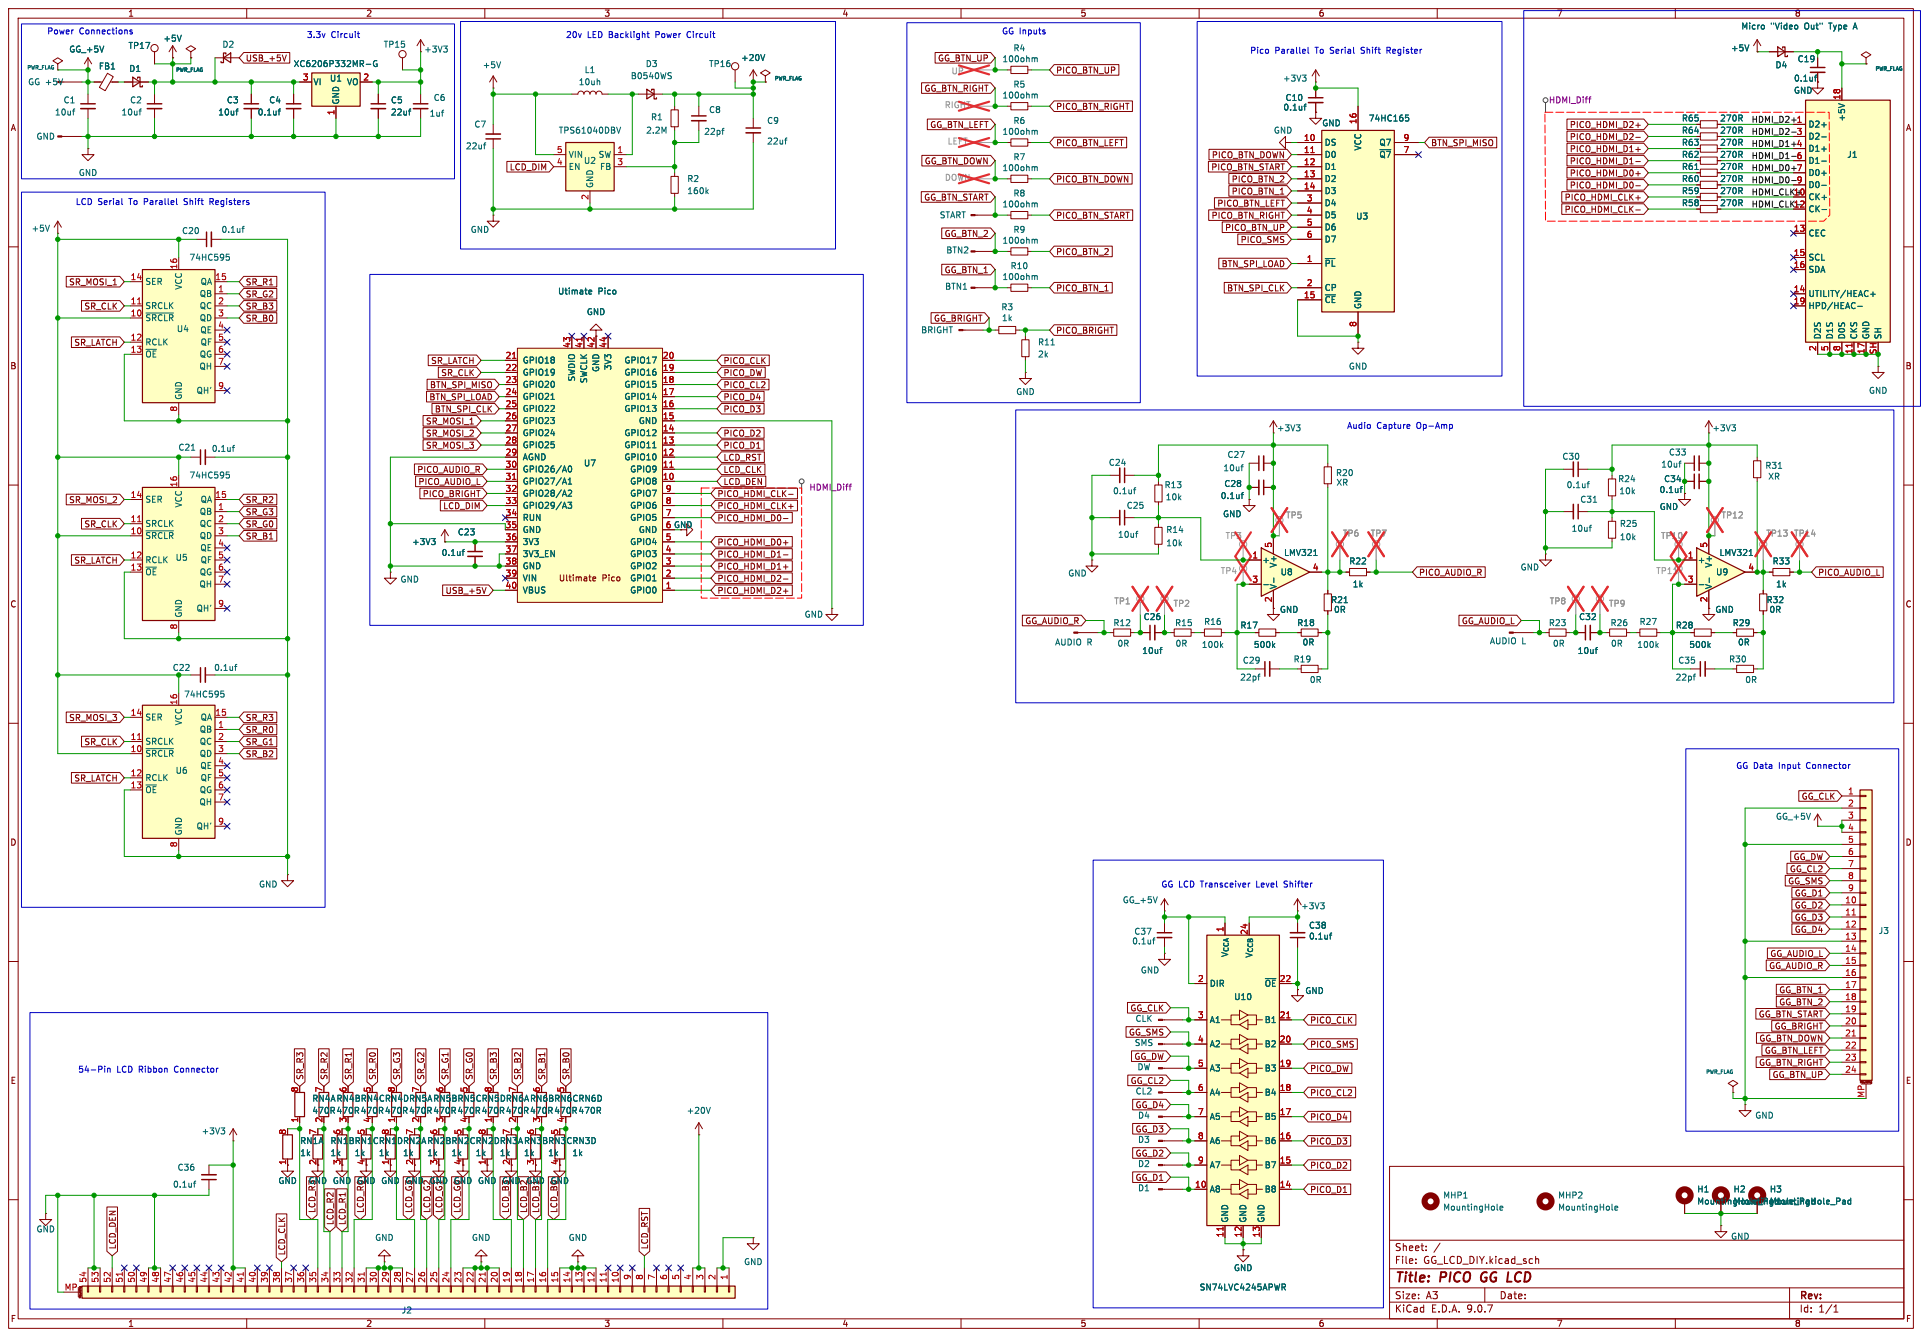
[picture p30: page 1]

J1 Micro "Video Out" Type A

8 CKS 11 GND 17 SH SH

GG Data Input Connector

File: GG_LCD_DIY.kicad_sch Sheet: /
Id: 1/1 Title: PICO GG LCD

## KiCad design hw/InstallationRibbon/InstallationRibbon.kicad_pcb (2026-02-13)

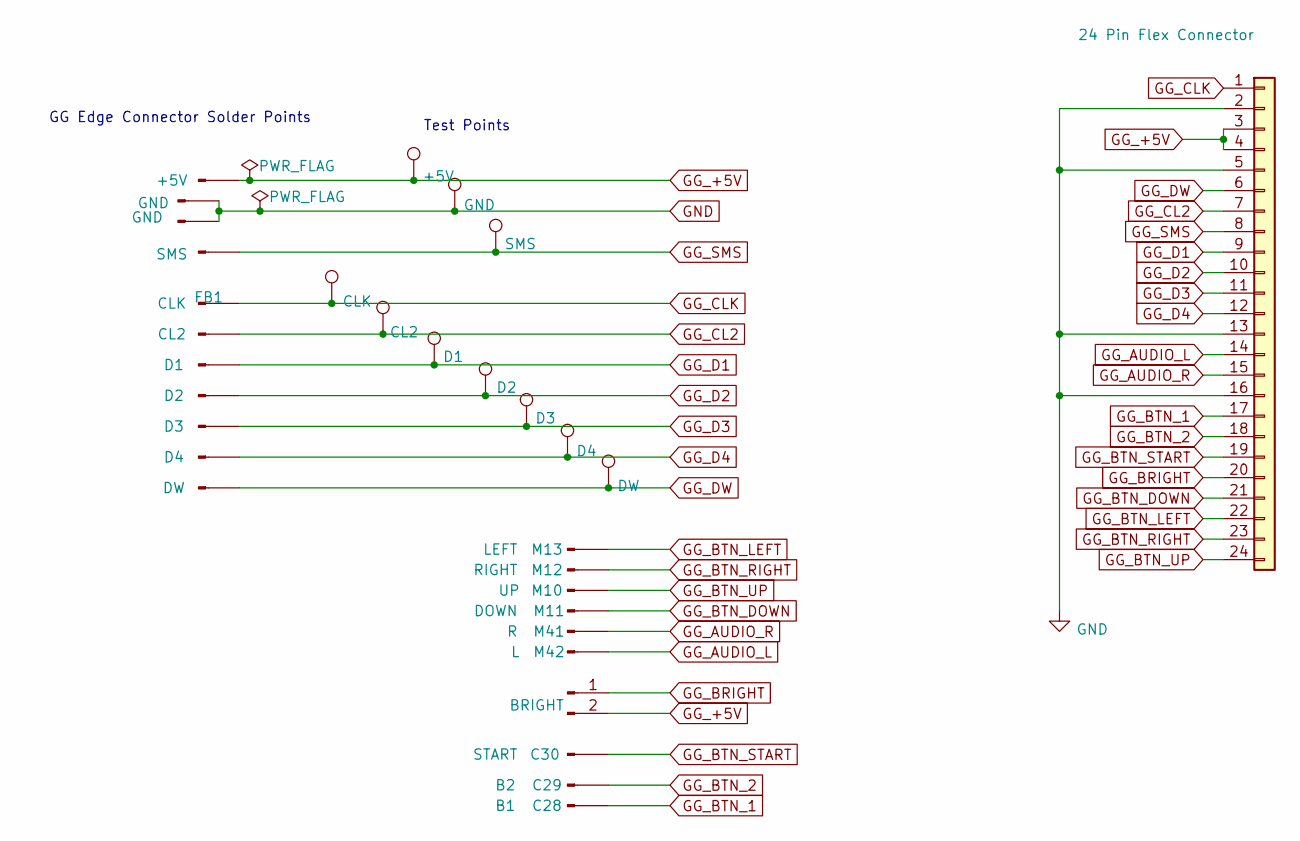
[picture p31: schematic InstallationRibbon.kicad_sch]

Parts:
J1: +5V; TestPoint_THTPad_D2.5mm_Drill1.2mm
J3: CLK; TestPoint_THTPad_D2.5x2.5mm_Drill1.2mm
J4: SMS; TestPoint_THTPad_D2.5mm_Drill1.2mm
J5: DW; SolderWirePad_1x01_EdgeWithHole_1x2mm
J6: CL2; SolderWirePad_1x01_EdgeWithHole_1x2mm
J7: D1; SolderWirePad_1x01_EdgeWithHole_1x2mm
J8: D2; SolderWirePad_1x01_EdgeWithHole_1x2mm
J9: D3; SolderWirePad_1x01_EdgeWithHole_1x2mm
J10: D4; SolderWirePad_1x01_EdgeWithHole_1x2mm
J12: LEFT; TestPoint_THTPad_D2.5mm_Drill1.2mm
J13: RIGHT; TestPoint_THTPad_D2.5mm_Drill1.2mm
J14: UP; TestPoint_THTPad_D2.5mm_Drill1.2mm
J15, J16: GND; TestPoint_THTPad_D2.5mm_Drill1.2mm
J17: 24 Pin Flex Connector; Flex Connector 0.5mm 01x24Pin
J18: DOWN; TestPoint_THTPad_D2.5mm_Drill1.2mm
J19: R; TestPoint_THTPad_D2.5mm_Drill1.2mm
J20: L; TestPoint_THTPad_D2.5mm_Drill1.2mm
J21: START; TestPoint_THTPad_D2.5x2.5mm_Drill1.2mm
J22: B2; TestPoint_THTPad_D2.5x2.5mm_Drill1.2mm
J23: B1; TestPoint_THTPad_D2.5x2.5mm_Drill1.2mm
J25: BRIGHT; TestPoint_2Pads_Pitch2.00mm_Drill1.0mm_OneSide
TP1: +5V; TestPoint_Pad_2.0x2.0mm
TP2: GND; TestPoint_Pad_2.0x2.0mm
TP3: CLK; TestPoint_Pad_2.0x2.0mm
TP4: SMS; TestPoint_Pad_2.0x2.0mm
TP5: DW; TestPoint_Pad_2.0x2.0mm
TP6: CL2; TestPoint_Pad_2.0x2.0mm
TP7: D4; TestPoint_Pad_2.0x2.0mm
TP8: D3; TestPoint_Pad_2.0x2.0mm
TP9: D2; TestPoint_Pad_2.0x2.0mm
TP10: D1; TestPoint_Pad_2.0x2.0mm

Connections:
GG_+5V: J1.1, J17.3, J17.4, J25.2, TP1.1
GG_AUDIO_L: J17.14, J20.1
GG_AUDIO_R: J17.15, J19.1
GG_BRIGHT: J17.20, J25.1
GG_BTN_1: J17.17, J23.1
GG_BTN_2: J17.18, J22.1
GG_BTN_DOWN: J17.21, J18.1
GG_BTN_LEFT: J12.1, J17.22
GG_BTN_RIGHT: J13.1, J17.23
GG_BTN_START: J17.19, J21.1
GG_BTN_UP: J14.1, J17.24
GG_CL2: J6.1, J17.7, TP6.1
GG_CLK: J3.1, J17.1, TP3.1
GG_D1: J7.1, J17.9, TP10.1
GG_D2: J8.1, J17.10, TP9.1
GG_D3: J9.1, J17.11, TP8.1
GG_D4: J10.1, J17.12, TP7.1
GG_DW: J5.1, J17.6, TP5.1
GG_SMS: J4.1, J17.8, TP4.1
GND: J15.1, J16.1, J17.2, J17.5, J17.13, J17.16, TP2.1

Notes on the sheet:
Test Points
GG Edge Connector Solder Points

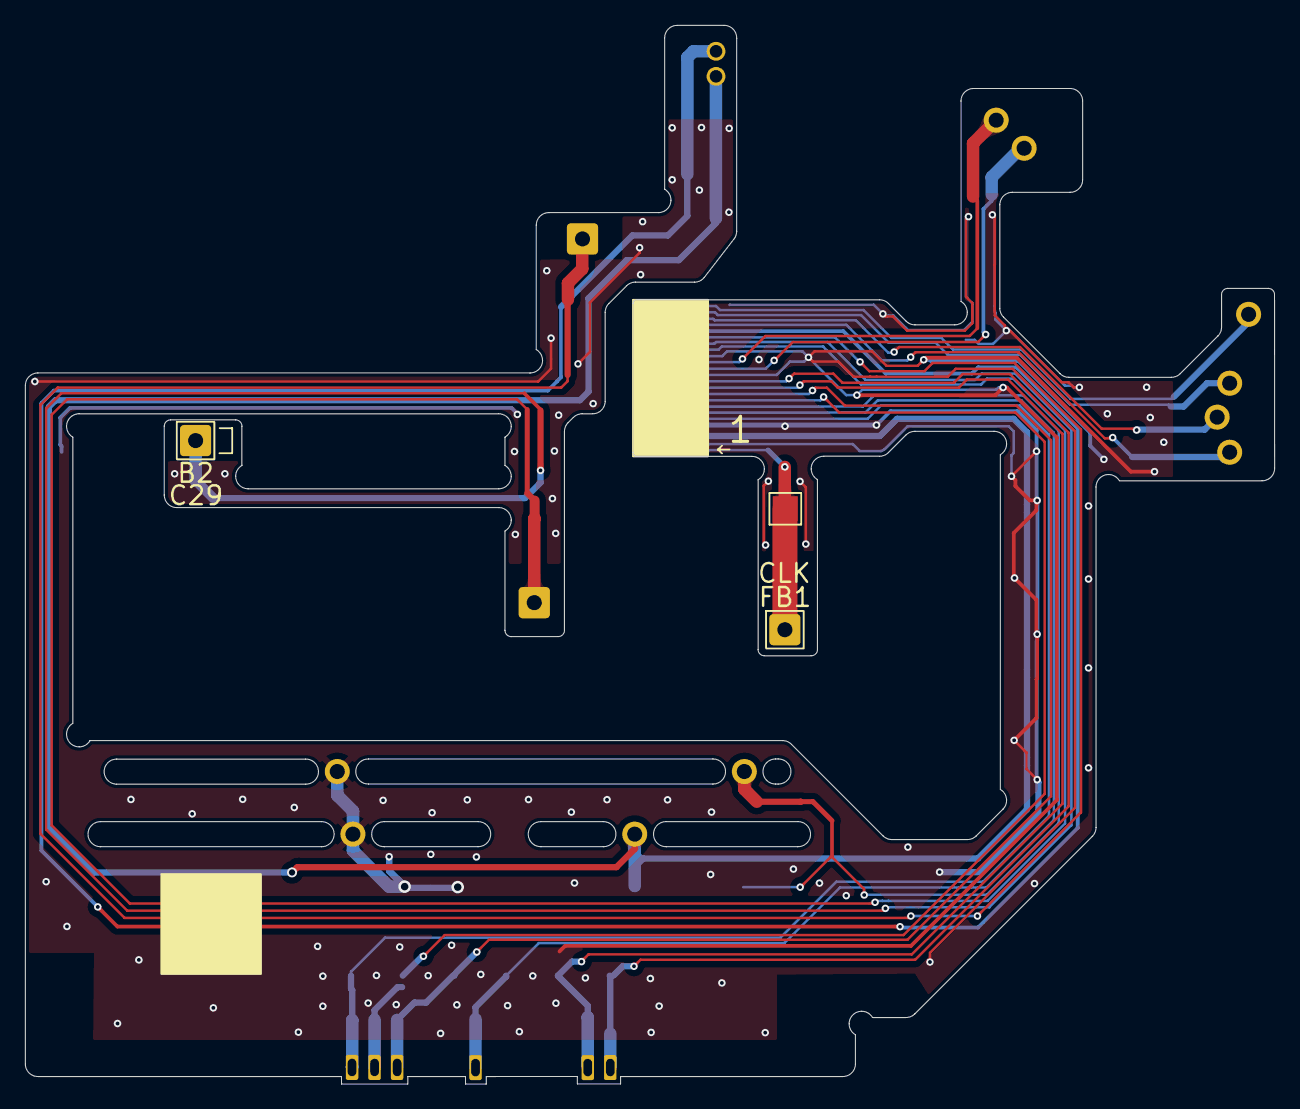
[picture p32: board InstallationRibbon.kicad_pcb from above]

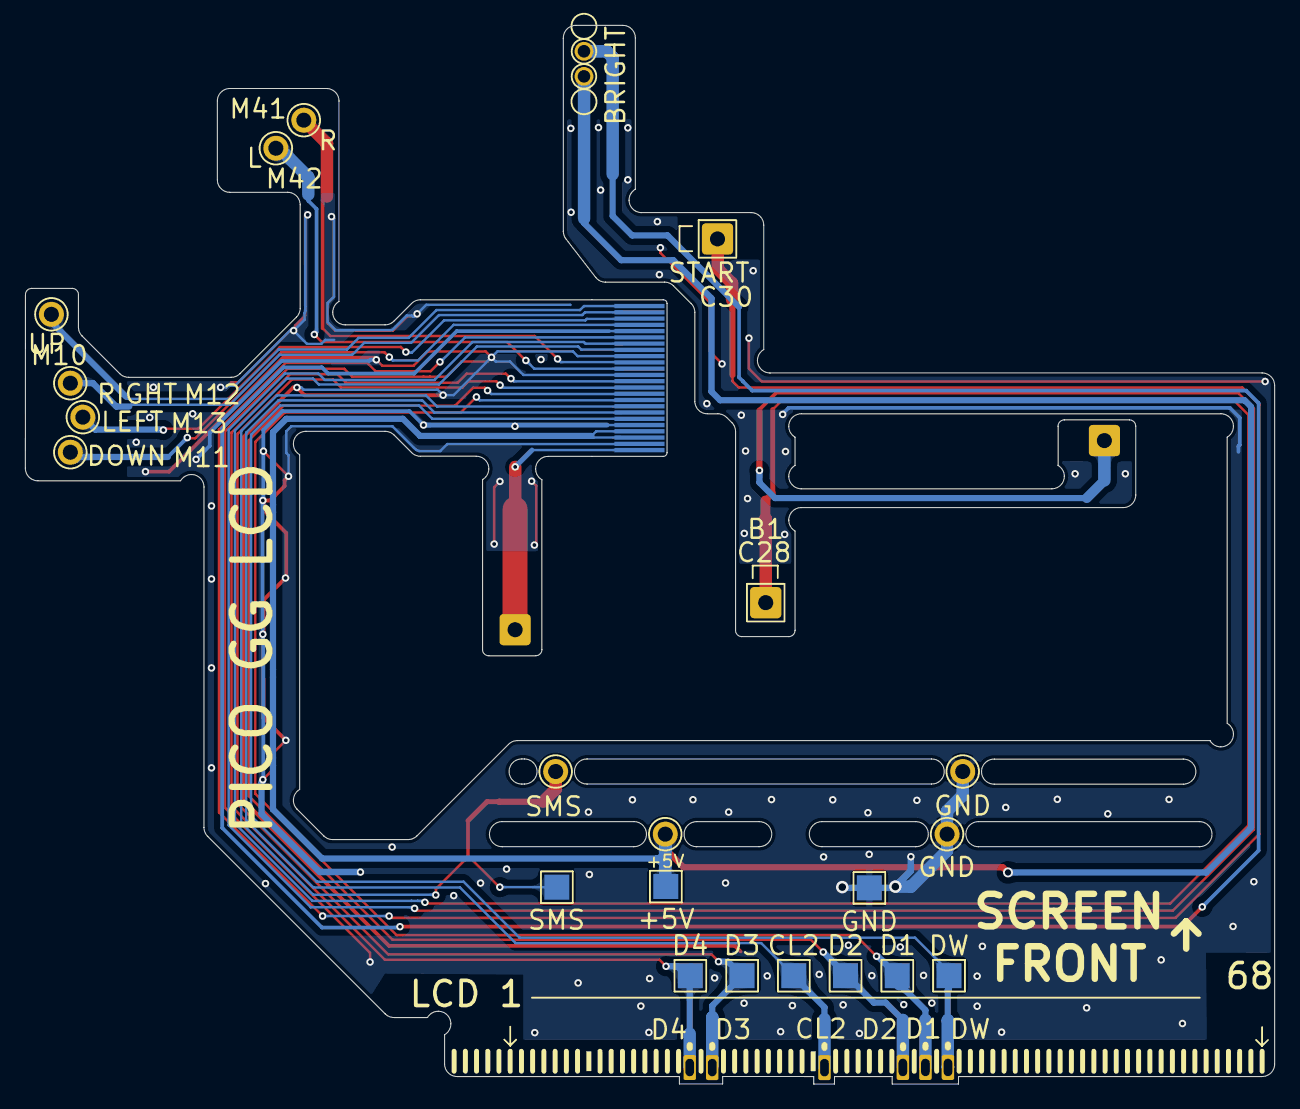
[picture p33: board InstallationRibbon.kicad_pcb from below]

Board: 2 copper layers, 99.7 x 84.5 mm, 32 parts (29 on the bottom side), 20 nets.

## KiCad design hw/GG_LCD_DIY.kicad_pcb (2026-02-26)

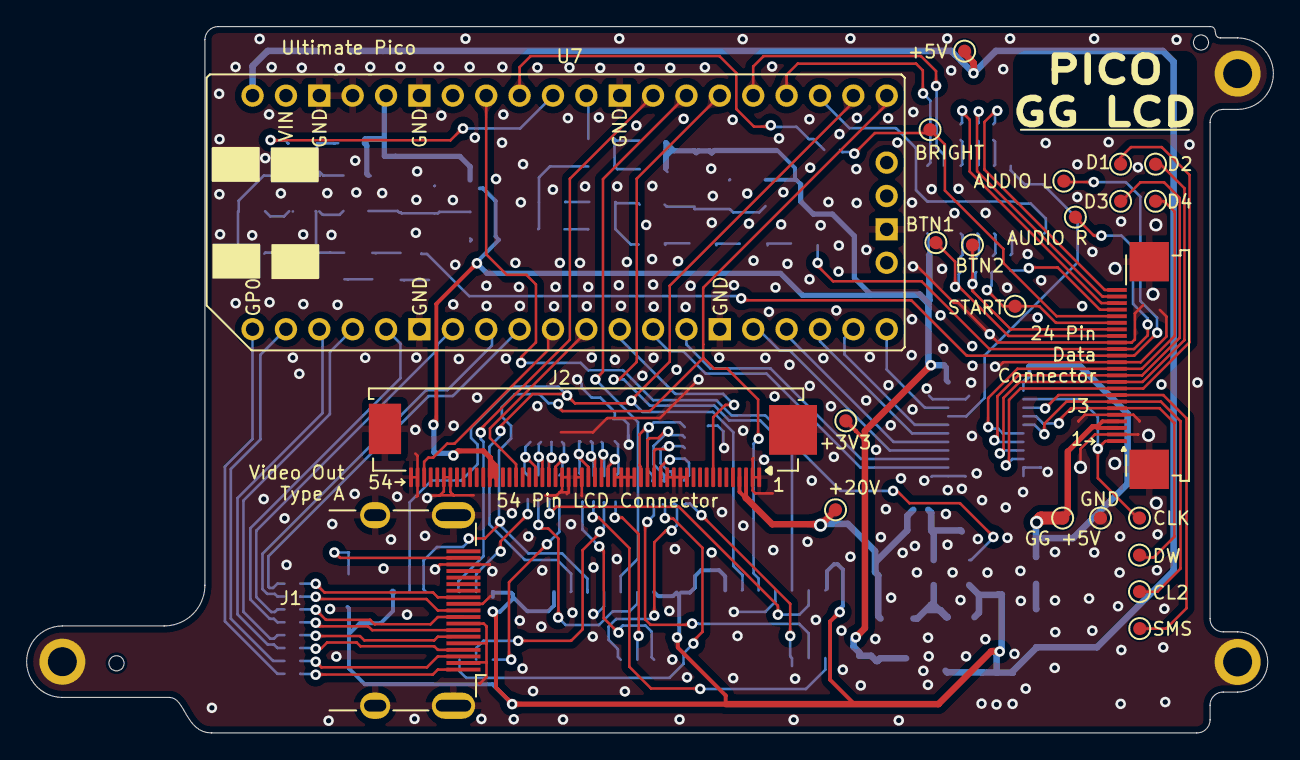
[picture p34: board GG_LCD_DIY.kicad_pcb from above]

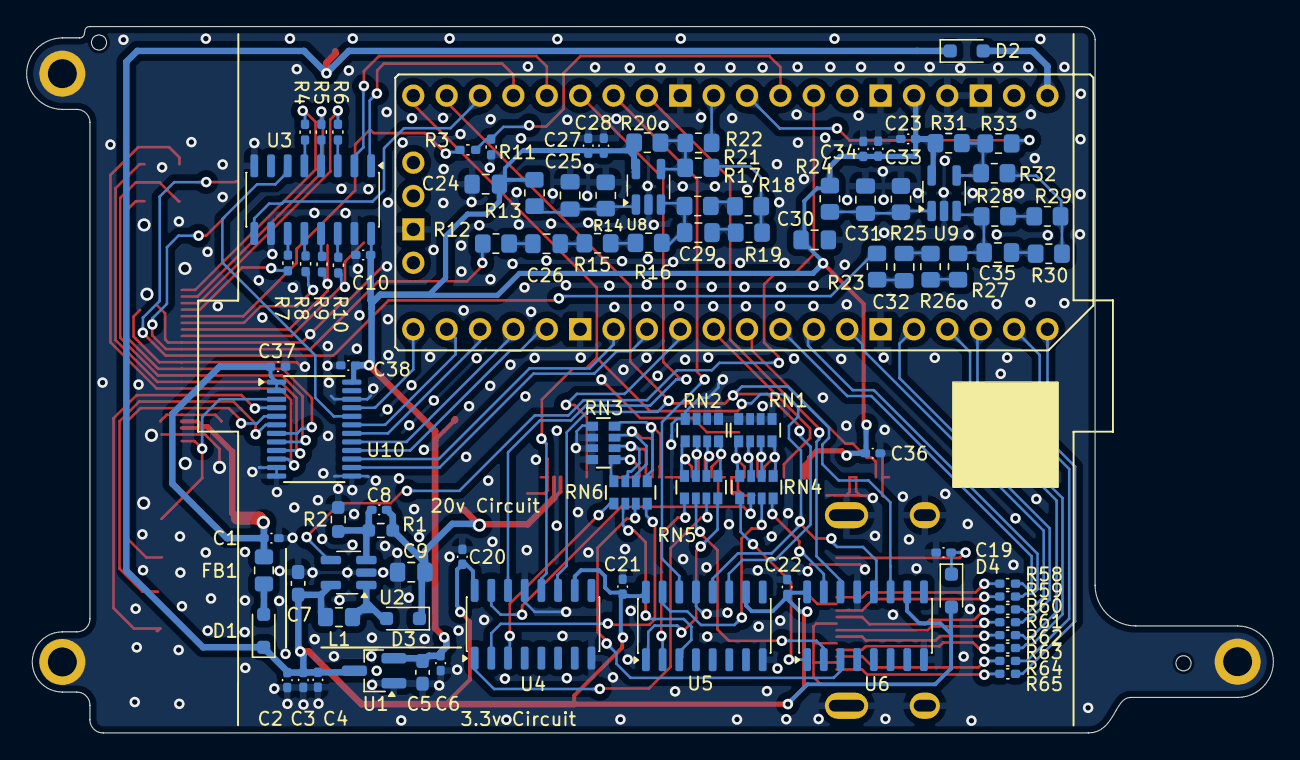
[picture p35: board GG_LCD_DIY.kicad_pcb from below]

Board: 2 copper layers, 94.9 x 53.8 mm, 121 parts (92 on the bottom side), 116 nets.

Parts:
C1, C2, C3, C27, C33: 10uf; C_0402_1005Metric_Pad0.74x0.62mm_HandSolder
C4, C10, C19, C20, C21, C22, C23, C28, C34, C36, C37, C38: 0.1uf; C_0402_1005Metric_Pad0.74x0.62mm_HandSolder
C5, C7: 22uf; C_0603_1608Metric_Pad1.08x0.95mm_HandSolder
C6: 1uf; C_0402_1005Metric_Pad0.74x0.62mm_HandSolder
C8: 22pf; C_0402_1005Metric_Pad0.74x0.62mm_HandSolder
C9: 22uf; C_0805_2012Metric_Pad1.18x1.45mm_HandSolder
C24, C30: 0.1uf; C_0805_2012Metric_Pad1.18x1.45mm_HandSolder
C25, C26, C31, C32: 10uf; C_0805_2012Metric_Pad1.18x1.45mm_HandSolder
C29, C35: 22pf; C_0805_2012Metric_Pad1.18x1.45mm_HandSolder
D1, D2, D3, D4: B0540WS; D_SOD-323_HandSoldering
FB1: GZ2012D601TF; L_0805_2012Metric_Pad1.15x1.40mm_HandSolder
H1, H2, H3: MountingHole_Pad; MountingHole_2.2mm_M2_ISO7380_Pad
J1: Micro "Video Out" Type A; HDMI_A_Molex_208658-1001_Horizontal
J2: Conn_01x54; 1x54 FPC Connector 0.5mm HandSolder
J3: 01x24 Conn; Jushuo_AFC07-S24FCA-00_1x24-1MP_P0.50_Horizontal
L1: 10uh; L_0805_2012Metric_Pad1.15x1.40mm_HandSolder
LCD1: lcd_template_with_ribbon
MHP1, MHP2: MountingHole; ToolingHole_1.152mm
R1: 2.2M; R_0603_1608Metric_Pad0.98x0.95mm_HandSolder
R2: 160k; R_0603_1608Metric_Pad0.98x0.95mm_HandSolder
R3: 1k; R_0402_1005Metric_Pad0.72x0.64mm_HandSolder
R4, R5, R6, R7, R8, R9, R10: 100ohm; R_0402_1005Metric_Pad0.72x0.64mm_HandSolder
R11: 2k; R_0402_1005Metric_Pad0.72x0.64mm_HandSolder
R12, R15, R18, R19, R21, R23, R26, R29, R30, R32: 0R; R_0805_2012Metric_Pad1.20x1.40mm_HandSolder
R13, R14, R24, R25: 10k; R_0805_2012Metric_Pad1.20x1.40mm_HandSolder
R16, R27: 100k; R_0805_2012Metric_Pad1.20x1.40mm_HandSolder
R17, R28: 500k; R_0805_2012Metric_Pad1.20x1.40mm_HandSolder
R20, R31: XR; R_0805_2012Metric_Pad1.20x1.40mm_HandSolder
R22, R33: 1k; R_0805_2012Metric_Pad1.20x1.40mm_HandSolder
R58, R59, R60, R61, R62, R63, R64, R65: 270R; R_0402_1005Metric_Pad0.72x0.64mm_HandSolder
RN1, RN2, RN3: 1k; R_Array_Convex_4x0603
RN4, RN5, RN6: 470R; R_Array_Convex_4x0603
T1: GG +5V; TestPoint_Pad_D1.0mm
T2: GND; TestPoint_Pad_D1.0mm
T3: BRIGHT; TestPoint_Pad_D1.0mm
T4: START; TestPoint_Pad_D1.0mm
T5: BTN2; TestPoint_Pad_D1.0mm
T6: BTN1; TestPoint_Pad_D1.0mm
T11: AUDIO L; TestPoint_Pad_D1.0mm
T12: AUDIO R; TestPoint_Pad_D1.0mm
T13: CLK; TestPoint_Pad_D1.0mm
T14: SMS; TestPoint_Pad_D1.0mm
T15: DW; TestPoint_Pad_D1.0mm
T16: CL2; TestPoint_Pad_D1.0mm
T17: D4; TestPoint_Pad_D1.0mm
T18: D3; TestPoint_Pad_D1.0mm
T19: D2; TestPoint_Pad_D1.0mm
T20: D1; TestPoint_Pad_D1.0mm
TP15: +3V3; TestPoint_Pad_D1.0mm
TP16: +20V; TestPoint_Pad_D1.0mm
TP17: +5V; TestPoint_Pad_D1.0mm
U1: XC6206P332MR-G; SOT-23_Handsoldering
U2: TPS61040DBV; SOT-23-5_HandSoldering
U3: 74HC165; SO-16_3.9x9.9mm_P1.27mm
U4, U5, U6: 74HC595; SO-16_3.9x9.9mm_P1.27mm
U7: Utimate Pico; RPi_Pico_SMD_TH_NoPads
U8, U9: LMV321; SOT-23-5_HandSoldering
U10: SN74LVC4245APWR; TSSOP-24_4.4x7.8mm_P0.65mm

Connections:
+3V3: C5.1, C6.1, C10.1, C23.1, C24.1, C27.2, C28.1, C30.1, C33.2, C34.2, C36.2, C38.2, J2.41, J2.42, R13.1, R20.2, R24.1, R31.2, TP15.1, U1.2 (VO), U3.16 (VCC), U7.36 (3V3), U8.5 (V+), U9.5 (V+), U10.24 (V_{CCB})
+5V: C2.1, C3.1, C4.1, C7.2, C20.1, C21.1, C22.1, D1.1 (K), D2.1 (K), D4.2 (A), L1.1, TP17.1, U1.3 (VI), U2.5 (VIN), U4.10 (~SRCLR), U4.16 (VCC), U5.10 (~SRCLR), U5.16 (VCC), U6.10 (~SRCLR), U6.16 (VCC)
+20V: C8.1, C9.1, D3.1 (K), J2.3, J2.4, R1.1, TP16.1
/HDMI_CLK+: J1.10 (CK+), R59.1
/HDMI_CLK-: J1.12 (CK-), R58.1
/HDMI_D0+: J1.7 (D0+), R61.1
/HDMI_D0-: J1.9 (D0-), R60.1
/HDMI_D1+: J1.4 (D1+), R63.1
/HDMI_D1-: J1.6 (D1-), R62.1
/HDMI_D2+: J1.1 (D2+), R65.1
/HDMI_D2-: J1.3 (D2-), R64.1
BTN_SPI_CLK: U3.2 (CP), U7.25 (GPIO22)
BTN_SPI_LOAD: U3.1 (~PL), U7.24 (GPIO21)
BTN_SPI_MISO: U3.9 (Q7), U7.23 (GPIO20)
GG_+5V: C1.1, C37.1, FB1.2, J3.3, J3.4, T1.1, U10.1 (V_{CCA}), U10.2 (DIR)
GG_AUDIO_L: J3.14, R23.1, T11.1
GG_AUDIO_R: J3.15, R12.1, T12.1
GG_BRIGHT: J3.20, R3.1, T3.1
GG_BTN_1: J3.17, R10.2, T6.1
GG_BTN_2: J3.18, R9.2, T5.1
GG_BTN_DOWN: J3.21, R7.2
GG_BTN_LEFT: J3.22, R6.2
GG_BTN_RIGHT: J3.23, R5.2
GG_BTN_START: J3.19, R8.2, T4.1
GG_BTN_UP: J3.24, R4.2
GG_CL2: J3.7, T16.1, U10.6 (A4)
GG_CLK: J3.1, T13.1, U10.3 (A1)
GG_D1: J3.9, T20.1, U10.10 (A8)
GG_D2: J3.10, T19.1, U10.9 (A7)
GG_D3: J3.11, T18.1, U10.8 (A6)
GG_D4: J3.12, T17.1, U10.7 (A5)
GG_DW: J3.6, T15.1, U10.5 (A3)
GG_SMS: J3.8, T14.1, U10.4 (A2)
GND: C1.2, C2.2, C3.2, C4.2, C5.2, C6.2, C7.1, C9.2, C10.2, C19.2, C20.2, C21.2, C22.2, C23.2, C24.2, C25.2, C27.1, C28.2, C30.2, C31.2, C33.1, C34.1, C36.1, C37.2, C38.1, H1.1, H2.1, H3.1, J1.2 (D2S), J1.5 (D1S), J1.8 (D0S), J1.11 (CKS), J1.17 (GND), J1.SH, J2.1, J2.2, J2.12, J2.13, J2.14, J2.15, J2.20, J2.21, J2.22, J2.23, J2.28, J2.29, J2.30, J2.31, J2.48, J2.49, J2.53, J2.54, J2.MP (MountPin), J3.2, J3.5, J3.13, J3.16, J3.MP (MountPin), R2.2, R11.2, R14.1, R25.1, RN1.1 (R1.1), RN1.2 (R2.1), RN1.3 (R3.1), RN1.4 (R4.1), RN2.1 (R1.1), RN2.2 (R2.1), RN2.3 (R3.1), RN2.4 (R4.1), RN3.1 (R1.1), RN3.2 (R2.1), RN3.3 (R3.1), RN3.4 (R4.1), T2.1, U1.1 (GND), U2.2 (GND), U3.8 (GND), U3.10 (DS), U3.15 (~CE), U4.8 (GND), U4.13 (~OE), U5.8 (GND), U5.13 (~OE), U6.8 (GND), U6.13 (~OE), U7.6 (GND), U7.15 (GND), U7.29 (AGND), U7.35 (GND), U7.37 (3V3_EN), U7.38 (GND), U7.42 (GND), U8.2 (V-), U9.2 (V-), U10.11 (GND), U10.12 (GND), U10.13 (GND), U10.22 (~OE)
LCD_B0: J2.16, RN3.5 (R4.2), RN6.4 (R4.1)
LCD_B1: J2.17, RN3.6 (R3.2), RN6.3 (R3.1)
LCD_B2: J2.18, RN3.7 (R2.2), RN6.2 (R2.1)
LCD_B3: J2.19, RN3.8 (R1.2), RN6.1 (R1.1)
LCD_CLK: J2.38, U7.11 (GPIO9)
LCD_DEN: J2.52, U7.10 (GPIO8)
LCD_DIM: U2.4 (EN), U7.33 (GPIO29/A3)
LCD_G0: J2.24, RN2.5 (R4.2), RN5.4 (R4.1)
LCD_G1: J2.25, RN2.6 (R3.2), RN5.3 (R3.1)
LCD_G2: J2.26, RN2.7 (R2.2), RN5.2 (R2.1)
LCD_G3: J2.27, RN2.8 (R1.2), RN5.1 (R1.1)
LCD_R0: J2.32, RN1.5 (R4.2), RN4.4 (R4.1)
LCD_R1: J2.33, RN1.6 (R3.2), RN4.3 (R3.1)
LCD_R2: J2.34, RN1.7 (R2.2), RN4.2 (R2.1)
LCD_R3: J2.35, RN1.8 (R1.2), RN4.1 (R1.1)
LCD_RST: J2.8, U7.12 (GPIO10)
unnamed: C26.1, R12.2
unnamed: C26.2, R15.1
unnamed: C29.2, R19.1
unnamed: C32.1, R23.2
unnamed: C32.2, R26.1
unnamed: C35.2, R30.1
unnamed: D1.2 (A), FB1.1
unnamed: D3.2 (A), L1.2, U2.1 (SW)
unnamed: C19.1, D4.1 (K), J1.18 (+5V)
unnamed: R15.2, R16.2
unnamed: R17.1, R18.1
unnamed: R18.2, R19.2, R21.1
unnamed: R20.1, R21.2, R22.2, U8.4
unnamed: R26.2, R27.2
unnamed: R28.1, R29.1
unnamed: R29.2, R30.2, R32.1
unnamed: R31.1, R32.2, R33.2, U9.4
unnamed: C8.2, R1.2, R2.1, U2.3 (FB)
unnamed: C25.1, R13.2, R14.2, U8.1 (+)
unnamed: C29.1, R16.1, R17.2, U8.3 (-)
unnamed: C31.1, R24.2, R25.2, U9.1 (+)
unnamed: C35.1, R27.1, R28.2, U9.3 (-)
PICO_AUDIO_L: R33.1, U7.31 (GPIO27/A1)
PICO_AUDIO_R: R22.1, U7.30 (GPIO26/A0)
PICO_BRIGHT: R3.2, R11.1, U7.32 (GPIO28/A2)
PICO_BTN_1: R10.1, U3.14 (D3)
PICO_BTN_2: R9.1, U3.13 (D2)
PICO_BTN_DOWN: R7.1, U3.11 (D0)
PICO_BTN_LEFT: R6.1, U3.3 (D4)
PICO_BTN_RIGHT: R5.1, U3.4 (D5)
PICO_BTN_START: R8.1, U3.12 (D1)
PICO_BTN_UP: R4.1, U3.5 (D6)
PICO_CL2: U7.18 (GPIO15), U10.18 (B4)
PICO_CLK: U7.20 (GPIO17), U10.21 (B1)
PICO_D1: U7.13 (GPIO11), U10.14 (B8)
PICO_D2: U7.14 (GPIO12), U10.15 (B7)
PICO_D3: U7.16 (GPIO13), U10.16 (B6)
PICO_D4: U7.17 (GPIO14), U10.17 (B5)
PICO_DW: U7.19 (GPIO16), U10.19 (B3)
PICO_HDMI_CLK+: R59.2, U7.8 (GPIO6)
PICO_HDMI_CLK-: R58.2, U7.9 (GPIO7)
PICO_HDMI_D0+: R61.2, U7.5 (GPIO4)
PICO_HDMI_D0-: R60.2, U7.7 (GPIO5)
PICO_HDMI_D1+: R63.2, U7.3 (GPIO2)
PICO_HDMI_D1-: R62.2, U7.4 (GPIO3)
PICO_HDMI_D2+: R65.2, U7.1 (GPIO0)
PICO_HDMI_D2-: R64.2, U7.2 (GPIO1)
PICO_SMS: U3.6 (D7), U10.20 (B2)
SR_B0: RN6.5 (R4.2), U4.3 (QD)
SR_B1: RN6.6 (R3.2), U5.3 (QD)
SR_B2: RN6.7 (R2.2), U6.3 (QD)
SR_B3: RN6.8 (R1.2), U4.2 (QC)
SR_CLK: U4.11 (SRCLK), U5.11 (SRCLK), U6.11 (SRCLK), U7.22 (GPIO19)
SR_G0: RN5.5 (R4.2), U5.2 (QC)
SR_G1: RN5.6 (R3.2), U6.2 (QC)
SR_G2: RN5.7 (R2.2), U4.1 (QB)
SR_G3: RN5.8 (R1.2), U5.1 (QB)
SR_LATCH: U4.12 (RCLK), U5.12 (RCLK), U6.12 (RCLK), U7.21 (GPIO18)
SR_MOSI_1: U4.14 (SER), U7.26 (GPIO23)
SR_MOSI_2: U5.14 (SER), U7.27 (GPIO24)
SR_MOSI_3: U6.14 (SER), U7.28 (GPIO25)
SR_R0: RN4.5 (R4.2), U6.1 (QB)
SR_R1: RN4.6 (R3.2), U4.15 (QA)
SR_R2: RN4.7 (R2.2), U5.15 (QA)
SR_R3: RN4.8 (R1.2), U6.15 (QA)
USB_+5V: D2.2 (A), U7.40 (VBUS)

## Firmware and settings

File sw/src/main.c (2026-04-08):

#include <stdio.h>
#include <string.h>
#include <math.h>
#include <stdint.h>
#include <stdlib.h>
#include "pico/multicore.h"

#include "hardware/pio.h"
#include "hardware/dma.h"
#include "pico/stdlib.h"
#include "pico/time.h"
#include "hardware/vreg.h"
#include "hardware/clocks.h"
#include "hardware/adc.h"
#include "hardware/structs/pwm.h"
#include "hardware/pwm.h"
//#include "hardware/interp.h"
#include "hardware/spi.h"

#include "../build/gg_capture.pio.h"
#include "../build/sms_capture.pio.h"
#include "../build/lcd_send_spi_2x.pio.h"
#include "../build/lcd_send_spi_4x.pio.h"
#include "font8x8_basic.h"

#include "libdvi/dvi.h"
#include "libdvi/dvi_serialiser.h"
#include "libdvi/dvi_timing.h"

#include "config_pins.h"
#include "main.h"


//Use two framebuffers to prevent tearing
uint16_t * framebuffer = (uint16_t *)(0x20000000 + (1024 * 40));
uint16_t * framebuffer2 = (uint16_t *)(0x20000000 + (1024 * 40) + FRAME_SIZE_BYTES);

uint32_t dma_chan_fb1_write;
uint32_t dma_chan_fb1_reset;
uint32_t dma_chan_fb2_write;
uint32_t dma_chan_fb2_reset;

//
//some pio configs
//
#define btn_sr_spi spi0

#define lcd_send_pio pio0 
#define lcd_send_sm 2

#define lcd_send_clk_pio pio0
#define lcd_send_clk_sm 3

#define gg_capture_pio pio0
#define gg_capture_hblank_sm 0 
#define gg_capture_getdata_sm 1 


//some lcd configs for gg
#define lcd_pio_hscale_gg 4
#define lcd_hscale_factor_gg 1 / lcd_pio_hscale_gg

#define lcd_target_width_gg 640
#define lcd_send_width_gg 160 //lcd_target_width * lcd_hscale_factor

//add extra pixels to the h porch
#define lcd_hblank_sync_len_gg 2 * lcd_hscale_factor_gg // 2
#define lcd_hblank_front_len_gg 44 * lcd_hscale_factor_gg  //24
#define lcd_hblank_back_len_gg 42 * lcd_hscale_factor_gg  //12
#define lcd_hblank_len_gg lcd_hblank_front_len_gg + lcd_send_width_gg + lcd_hblank_back_len_gg //this is sync plus both porches plus active display area

#define lcd_active_lines_gg 160 // 160 * 3x scale = 480 lcd lines
#define lcd_vscale_factor_gg 3



//some lcd configs for sms
#define lcd_pio_hscale_sms 2
#define lcd_hscale_factor_sms 1 / lcd_pio_hscale_sms

#define lcd_target_width_sms 640
#define lcd_send_width_sms 320 //lcd_target_width * lcd_hscale_factor

//add extra pixels to the h porch
#define lcd_hblank_sync_len_sms 2 * lcd_hscale_factor_sms // 2
#define lcd_hblank_front_len_sms 44 * lcd_hscale_factor_sms  //24
#define lcd_hblank_back_len_sms 42 * lcd_hscale_factor_sms  //12
#define lcd_hblank_len_sms lcd_hblank_front_len_sms + lcd_send_width_sms + lcd_hblank_back_len_sms //this is sync plus both porches plus active display area

#define lcd_active_lines_sms 240 // 160 * 3x scale = 480 lcd lines
#define lcd_vscale_factor_sms 2



#define lcd_vblank_sync_lines 2 
#define lcd_vblank_front_lines 16 //22 
#define lcd_vblank_back_lines 14 //88 


//
//libdvi config
//

#define dvi_pio pio1
#define dvi_tmds_sm_0 0
#define dvi_tmds_sm_1 1
#define dvi_tmds_sm_2 2

// DVDD 1.2V (1.1V seems ok too)
//#define FRAME_WIDTH 320
//#define FRAME_HEIGHT 240
#define VREG_VSEL VREG_VOLTAGE_1_20

#define DVI_TIMING dvi_timing_640x480p_60hz

struct dvi_inst dvi0;

static struct dvi_serialiser_cfg pico_gg_lcd_conf = {
	.pio = dvi_pio,
	.sm_tmds = {dvi_tmds_sm_0, dvi_tmds_sm_1, dvi_tmds_sm_2},
	.pins_tmds = {dvi_d0_pins_base, dvi_d1_pins_base, dvi_d2_pins_base},
	.pins_clk = dvi_clk_pins_base,
	.invert_diffpairs = false
};

#define DVI_DMA_IRQ DMA_IRQ_0

#define DVI_AUDIO_CTS 28000
#define DVI_AUDIO_BUFFER_SIZE 256
audio_sample_t dvi_audio_buffer[DVI_AUDIO_BUFFER_SIZE];


//
//ADC audio capture
//
#define AUDIO_SAMPLE_RATE 44100
#define AUDIO_CHANNEL_COUNT 4 //2 audio + 1 brightness potentiometer, but needs to be power of 2 for dma and ring buffer to work ok 
#define AUDIO_BUFFER_BITS 11
#define AUDIO_BUFFER_SIZE (1 << AUDIO_BUFFER_BITS)
//#define AUDIO_BUFFER_SIZE 1024

__attribute__((aligned((1 << AUDIO_BUFFER_BITS))))
__attribute__((section(".time_critical.ram")))
static uint16_t audio_buffer[AUDIO_BUFFER_SIZE];

static const uint32_t audio_buffer_addr = (uint32_t)audio_buffer;


//brightness potentiometer value
volatile uint32_t brightness = 0;
uint8_t pwm_backlight_slice;
#define brightness_factor 3.3f  //brightness potentiometer only seems to go up to 1v

//
//lcd dimming using pwm to influence the 20v regulator
//
#define pwm_wrap_target			1024
#define pwm_default_level		800
#define pwm_min_level			0 //300
#define pwm_clk_div 			16


//
//button states
//
bool is_gg = true;
bool gg_now = true;
bool last_gg = true;

bool gg_start_now;
bool gg_btn1_now;
bool gg_btn2_now;
bool gg_btn_up_now;
bool gg_btn_dn_now;
bool gg_btn_lt_now;
bool gg_btn_rt_now;

bool gg_start_was;
bool gg_btn1_was;
bool gg_btn2_was;
bool gg_btn_up_was;
bool gg_btn_dn_was;
bool gg_btn_lt_was;
bool gg_btn_rt_was;

bool gg_start_changed;
bool gg_btn1_changed;
bool gg_btn2_changed;
bool gg_btn_up_changed;
bool gg_btn_dn_changed;
bool gg_btn_lt_changed;
bool gg_btn_rt_changed;

bool gg_start_pressed;
bool gg_btn1_pressed;
bool gg_btn2_pressed;
bool gg_btn_up_pressed;
bool gg_btn_dn_pressed;
bool gg_btn_lt_pressed;
bool gg_btn_rt_pressed;

bool gg_start_released;
bool gg_btn1_released;
bool gg_btn2_released;
bool gg_btn_up_released;
bool gg_btn_dn_released;
bool gg_btn_lt_released;
bool gg_btn_rt_released;

uint32_t startup_time;


//
//lcd update methods
//

static inline __attribute__ ((always_inline)) void send_lcd_pixel(uint16_t data)
{
	pio_sm_put(lcd_send_pio, lcd_send_sm, (uint32_t)data);
}

//used for blanking periods
static inline __attribute__ ((always_inline)) void send_4blank_lcd_pixel()
{
	while(!pio_sm_is_tx_fifo_empty(lcd_send_pio, lcd_send_sm)) ;

	pio_sm_put(lcd_send_pio, lcd_send_sm, 0);
	pio_sm_put(lcd_send_pio, lcd_send_sm, 0);
	pio_sm_put(lcd_send_pio, lcd_send_sm, 0);
	pio_sm_put(lcd_send_pio, lcd_send_sm, 0);

}
static inline __attribute__ ((always_inline)) void send_2blank_lcd_pixel()
{
	while(!pio_sm_is_tx_fifo_empty(lcd_send_pio, lcd_send_sm)) ;

	pio_sm_put(lcd_send_pio, lcd_send_sm, 0);
	pio_sm_put(lcd_send_pio, lcd_send_sm, 0);

}

volatile uint32_t for_nop_count = 0;

//changes the data-enable signal, but waits for any previous pixels to be completely sent through the shift registers via PIO interupt
static inline __attribute__ ((always_inline)) void lcd_den_set(bool lcd_den_value, bool skip_interrupt) 
{
	while(!pio_sm_is_tx_fifo_empty(lcd_send_pio, lcd_send_sm));

	for(for_nop_count = 0; for_nop_count < 5; for_nop_count++)
	{
		__asm volatile("nop");
	}
	
	//wait for pio interrupt to flag it's stalled and waiting for bytes
	while(!skip_interrupt && !pio_interrupt_get(lcd_send_pio, 4));

	gpio_put(lcd_den, lcd_den_value);
	
}

/*
static inline __attribute__ ((always_inline)) uint32_t unpack(uint32_t rgb_value) {
	uint32_t temp = rgb_value >> 8;
	temp |= rgb_value << 20;
	temp |= rgb_value << 6;
	temp &= 0b111100000011110000001111;

	return temp;
}
*/


uint16_t * framebuffer_to_use;

//__attribute__ ((long_call, section (".time_critical"))) void update_lcd_gg(uint16_t * curr_framebuffer) {	
void update_lcd_gg(uint16_t * curr_framebuffer) {	

	//uint16_t spi_buffer[4] = {0x800, 0x800, 0x800, 0x800};  

	//Because of the LCD's orientation, we actually need to scan the image out upside down and flipped
	//base points to the bottom right of the original image
	uint32_t base = pixels_in_scanline + 48 - 52 + FRAME_SIZE_PIXELS - pixels_in_scanline * 51;

	static uint16_t line_diff = lcd_active_lines_gg - gg_pixel_height;
	uint16_t header_count = line_diff * 0.5;
	uint16_t footer_count = line_diff - header_count;

	uint32_t y_base;
	uint32_t y_base_offset = (gg_pixel_x_offset + (pixels_in_scanline - gg_pixel_width) * 0.5);
	uint32_t y_target;

	uint32_t blank_lines, blank_pixels, w, x, y;

	//might not need to skip interrupt?
	lcd_den_set(0, true);


	//start vsync pulse

	for(blank_lines = 0; blank_lines < lcd_vblank_sync_lines; blank_lines ++) {
		
		for(blank_pixels = 0; blank_pixels < lcd_hblank_sync_len_gg; blank_pixels +=4) {
			send_4blank_lcd_pixel();
		}

		for(blank_pixels = 0; blank_pixels < lcd_hblank_len_gg; blank_pixels +=4) {
			send_4blank_lcd_pixel();
		}
	}
	//end vsync pulse

	//start vsync back porch
	for(blank_lines = 0; blank_lines < lcd_vblank_back_lines; blank_lines ++) {
		
		for(blank_pixels = 0; blank_pixels < lcd_hblank_sync_len_gg; blank_pixels +=4) {
			send_4blank_lcd_pixel();
		}

		for(blank_pixels = 0; blank_pixels < lcd_hblank_len_gg; blank_pixels +=4) {
			send_4blank_lcd_pixel();
		}

	}
	//end vsync back porch



	//footer goes at the top when the frame is upside-down

	//frame footer
	//do some blank footer lines....
	for (y = gg_pixel_height; y < gg_pixel_height + footer_count; y++)
	{
		for (w = 0; w < lcd_vscale_factor_gg; w++)
		{
			for(blank_pixels = 0; blank_pixels < lcd_hblank_sync_len_gg; blank_pixels +=4) {
				send_4blank_lcd_pixel();
			}

			for(blank_pixels = 0; blank_pixels < lcd_hblank_back_len_gg; blank_pixels +=4) {
				send_4blank_lcd_pixel();
			}

			//y_base = y * pixels_in_scanline;			
			//y_base += (pixels_in_scanline - gg_pixel_width) * 0.5;
			//y_base += y_base_offset;

			lcd_den_set(1, false);

			//blank line
			//for (uint32_t x = y_base + lcd_send_width; x > y_base; x -=4)
			for (x = 0 ; x < lcd_send_width_gg; x +=4)
			{
				send_4blank_lcd_pixel();
			}
			
			//Signal end of active scanline portion
			lcd_den_set(0, false);
			
			//Send empty pixels during Hblank
			for(blank_pixels = 0; blank_pixels < lcd_hblank_front_len_gg; blank_pixels ++) {				
				send_4blank_lcd_pixel();
			}
			
		}
	}


	//frame body
	//start frame data - this reads from bottom line to top line so the frame is sent upside-down	
	for (y = gg_pixel_height + gg_v_lines_to_skip; y > gg_v_lines_to_skip ; y--)	
	{
		for (w = 0; w < lcd_vscale_factor_gg; w++)
		{
			for(blank_pixels = 0; blank_pixels < lcd_hblank_sync_len_gg; blank_pixels +=4) {
				send_4blank_lcd_pixel();
			}

			for(blank_pixels = 0; blank_pixels < lcd_hblank_back_len_gg; blank_pixels +=4) {
				send_4blank_lcd_pixel();
			}

			//Where in the framebuffer the current scanline starts
			//uint32_t y_base = base - ((y * 310) >> 9) * pixels_in_scanline + 256;

			y_base = (y-1) * pixels_in_scanline;			
			y_base += y_base_offset;

			//Tell LCD we're starting the active portion of the scanline
			lcd_den_set(1, false);

			///unpack transforms 0b0000rrrrggggbbbb word into 0bbbb000000gggg000000rrrr word
			//Channel order is changed to bgr because that's what the LCD expects
			//Channel bits are spread out so we can do SIMD-within-a-word
			//The interpolator will do linear interpolation on all three channels at once, using a single 32-bit word
			//uint32_t framebuffer_pix_value = curr_framebuffer[y_base] & 4095;
			//uint32_t old_pix_value = unpack(curr_framebuffer[y_base] & 4095);
			
			//for (uint32_t x = y_base; x < y_base + lcd_send_width; x +=4)
			for (x = y_base + lcd_send_width_gg-1; x >= y_base; x -=4)
			{

				//sub_pixel is a 24.8 bit fixed point coordinate
				
				//uint32_t sub_pixel = (x * 133);

				//Use integer part to pick a pixel from the framebuffer
				//uint32_t pixIndex = y_base - (sub_pixel >> 8);
				//uint32_t pixIndex = y_base - (x);
				//uint32_t pixIndex = y_base + (x);
				//uint32_t framebuffer_pix_value = curr_framebuffer[pixIndex] & 4095;

				//uint32_t new_pix_value = unpack(curr_framebuffer[pixIndex] & 4095);

				//Values to be interpolated
				//interp0->base[0] = old_pix_value;
				//interp0->base[1] = new_pix_value;

				//Fractional part of sub_pixel tells the interpolator how much of each pixel to use
				//interp0->accum[1] = sub_pixel & 0b11111100;

				//uint32_t pix_value = interp0->peek[1];
				//uint32_t pix_value = new_pix_value; //Uncomment this line to use nearest-neighbor instead of linear interpolation

				//old_pix_value = new_pix_value;
				
				//By the time we get here, the PIO is probably gonna be done sending the last pixel anyways
				while(!pio_sm_is_tx_fifo_empty(lcd_send_pio, lcd_send_sm)) ;

				//This way, we only have to poll on the FIFO status once and then can just blast the three words at once
				//Seems to be significantly faster than pio_sm_put_blocking on each word
				//pio_sm_put(lcd_send_pio, lcd_send_sm, pix_value & 15);
				//pix_value >>= 10;
				//pio_sm_put(lcd_send_pio, lcd_send_sm, pix_value & 15);
				//pix_value >>= 10;
				//pio_sm_put(lcd_send_pio, lcd_send_sm, pix_value & 15);

				send_lcd_pixel(curr_framebuffer[x]);
				send_lcd_pixel(curr_framebuffer[x-1]);
				send_lcd_pixel(curr_framebuffer[x-2]);
				send_lcd_pixel(curr_framebuffer[x-3]);
					
			}

			//Signal end of active scanline portion
			lcd_den_set(0, false);
			
			//Send empty pixels during Hblank front porch
			for(blank_pixels = 0; blank_pixels < lcd_hblank_front_len_gg; blank_pixels +=4) {
				send_4blank_lcd_pixel();
			}			
		}

	}

	//frame "header"
	//as the frame is output upside-down, the "header" goes at the bottom
	for (y = 0; y < header_count ; y++)
	{
		for (w = 0; w < lcd_vscale_factor_gg; w++)
		{
			for(blank_pixels = 0; blank_pixels < lcd_hblank_sync_len_gg; blank_pixels +=4) {	
				send_4blank_lcd_pixel();
			}

			for(blank_pixels = 0; blank_pixels < lcd_hblank_back_len_gg; blank_pixels +=4) {		
				send_4blank_lcd_pixel();
			}
			
			//repeat the bottom lines at the top
			//y_base = (gg_pixel_height + y) * pixels_in_scanline;			
			//y_base += y_base_offset;
			//y_target = y_base + lcd_send_width;
			
			lcd_den_set(1, false);
			
			//for (uint32_t x = y_base; x < y_target; x +=4) {			
			//for (uint32_t x = y_target; x > y_base; x -=4) {	
			for (x = 0; x < lcd_send_width_gg; x +=4) {

				while(!pio_sm_is_tx_fifo_empty(lcd_send_pio, lcd_send_sm)) ;
				send_4blank_lcd_pixel();
			}

			//Signal end of active scanline portion
			lcd_den_set(0, false);
			
			//Send empty pixels during Hblank
			for(blank_pixels = 0; blank_pixels < lcd_hblank_front_len_gg; blank_pixels +=4) {				
				send_4blank_lcd_pixel();
			}

		}
	}


	//Start of vblank
	//lcd_den_set(1, false);

	//end frame data

	//start vsync front porch

	//Start of vblank 
	//lcd_den_set(0, false);

	//Send empty data for the entirety of vblank
	 
	for(blank_pixels = 0; blank_pixels < lcd_hblank_sync_len_gg; blank_pixels +=4) {
		send_4blank_lcd_pixel();
	}

	for(blank_lines = 0; blank_lines < lcd_vblank_front_lines; blank_lines ++) {

		for(blank_pixels = 0; blank_pixels < lcd_hblank_len_gg; blank_pixels +=4) {
			send_4blank_lcd_pixel();
		}
	}
	//end vsync front porch
	
	//lcd_den_set(0, false);

}


/*
//The only thing that changes for SMS mode are the scaling constants
//However, putting those values in variables considerably slows down this function
//So, instead, we use magic constants baked into the code
__attribute__ ((long_call, section (".time_critical"))) void update_lcd_sms() {	
    while(!dma_channel_is_busy(dma_chan_fb1_write) && !dma_channel_is_busy(dma_chan_fb2_write)) ;
	uint16_t * curr_framebuffer;

	if(dma_channel_is_busy(dma_chan_fb1_write)) curr_framebuffer = framebuffer2;
	else curr_framebuffer = framebuffer;

	pio_sm_put_blocking(gg_capture_pio, gg_capture_hblank_sm, scanlines_in_active_area + scanlines_to_skip - 1);
	pio_sm_exec(gg_capture_pio, gg_capture_hblank_sm, pio_encode_pull(false, true));

	dma_hw->ch[2].transfer_count = pixels_in_scanline * scanlines_to_skip;
	dma_hw->ch[3].transfer_count = pixels_in_scanline * scanlines_to_skip;

	uint32_t line_counter = 0;
	uint32_t base = pixels_in_scanline + 256 + 48 - 3 + (FRAME_SIZE_PIXELS - pixels_in_scanline * 2;

	for (uint32_t y = 0; y < 240; y ++)
	{
		uint32_t y_base = base - ((y * 413) >> 9) * pixels_in_scanline;

		gpio_put(lcd_den, 0);

		uint32_t old_pix_value = unpack(curr_framebuffer[y_base] & 4095);

		for (uint32_t x = 0; x < 320; x ++)
		{
			uint32_t sub_pixel = (x * 210);
			uint32_t pixIndex = y_base - (sub_pixel >> 8);
			uint32_t new_pix_value = unpack(curr_framebuffer[pixIndex] & 4095);

			interp0->base[0] = old_pix_value;
			interp0->base[1] = new_pix_value;
			interp0->accum[1] = sub_pixel;

			uint32_t pix_value = interp0->peek[1];
			old_pix_value = new_pix_value;

			while(!pio_sm_is_tx_fifo_empty(lcd_send_pio, lcd_send_sm)) ;

			pio_sm_put(lcd_send_pio, lcd_send_sm, pix_value & 15);
			pix_value >>= 10;
			pio_sm_put(lcd_send_pio, lcd_send_sm, pix_value & 15);
			pix_value >>= 10;
			pio_sm_put(lcd_send_pio, lcd_send_sm, pix_value & 15);
		}

		gpio_put(lcd_den, 1);

		for(uint32_t wait = 0; wait < lcd_hblank_len; wait ++) {
			pio_sm_put_blocking(lcd_send_pio, lcd_send_sm, 0);
		}
	}

	gpio_put(lcd_den, 1);

	for(uint32_t wait_line = 0; wait_line < lcd_vblank_back_lines; wait_line ++) {
		for(uint32_t pixel = 0; pixel < lcd_send_width; pixel ++) {
			for(uint32_t channel = 0; channel < lcd_channels; channel ++) {
				pio_sm_put_blocking(lcd_send_pio, lcd_send_sm, 0);
			}
		}

		for(uint32_t wait = 0; wait < lcd_hblank_len; wait ++) {
			pio_sm_put_blocking(lcd_send_pio, lcd_send_sm, 0);
		}
	}
}
*/
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
int main() 
{
	init();

	multicore_reset_core1();

	multicore_launch_core1(core1_main); //libdvi core

	core0_main(); //main lcd core

	return 0;
}
 

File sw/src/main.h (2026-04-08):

#pragma once


#define gg_clock_khz 32215.9 //32.215mhz game gear "sub-pixel" clock

#define pixels_in_scanline 256 
#define scanlines_in_active_area  193  

#define FRAME_SIZE_PIXELS (pixels_in_scanline * scanlines_in_active_area)
#define FRAME_SIZE_BYTES (FRAME_SIZE_PIXELS * 2)

#define gg_v_lines_to_skip 49
//#define gg_h_pixels_to_skip 64

#define gg_pixel_width 160
#define gg_pixel_height 144
#define gg_pixel_x_offset 40 
#define gg_pixel_x_offset_dvi 40 


#define sms_v_lines_to_skip 1
//#define sms_h_pixels_to_skip 90

#define sms_pixel_width 256
#define sms_pixel_height 192
#define sms_pixel_x_offset 0 
#define sms_pixel_x_offset_dvi 0 


#ifndef DVI_VERTICAL_REPEAT_GG
#define DVI_VERTICAL_REPEAT_GG 3
#endif

#ifndef DVI_VERTICAL_REPEAT_SMS
#define DVI_VERTICAL_REPEAT_SMS 2
#endif

extern bool is_gg;
extern bool gg_now;
extern bool last_gg;

void fill_framebuffer_with_test_pattern();

void set_backlight(uint16_t level);
uint8_t config_backlight_pwm();

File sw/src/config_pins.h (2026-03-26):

//pin config in separate file for when differnt pin configs end up being needed for different pcb versions...

#pragma once

//libdvi output
#define dvi_d2_pins_base 0
#define dvi_d1_pins_base 2
#define dvi_d0_pins_base 4
#define dvi_clk_pins_base 6

//direct to lcd control
#define lcd_den 8
#define lcd_clk 9
#define lcd_rst 10

//gg video capture
#define gg_D1_pin 11 
#define gg_D2_pin 12 
#define gg_D3_pin 13 
#define gg_D4_pin 14 

#define gg_cl2_pin 15   //hsync
#define gg_dw_pin 16    //vsync
//#define gg_clk_pin 17   //sub-pixel RGB clock - not needed in current build, virtual clock is derived using PIO clock divider


//serial-to-parallel lcd shift registers
#define lcd_spi_latch 18
#define lcd_spi_clk 19
#define lcd_spi_mosi_1 23
#define lcd_spi_mosi_2 24
#define lcd_spi_mosi_3 25

//parallel-to-serial "SMS/GG" and button inputs shift register
#define btn_sr_miso 20
#define btn_sr_load 21
#define btn_sr_clk 22

//adc audio capture
#define gg_audio_r_pin 26
#define gg_audio_l_pin 27

//adc brightness controls
#define brightness_pot 28
#define lcd_dim 29

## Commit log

2025-10-25 Added 54PinToRibbonAdapterBoard KiCad project
    [54PinTo60RibbonAdapterBoard-CuBottom.gbr, 54PinTo60RibbonAdapterBoard-CuTop.gbr, 54PinTo60RibbonAdapterBoard-EdgeCuts.gbr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]
2025-10-30 Updated FPC connector on 54 Pin Adapter Board
    [54PinTo60RibbonAdapterBoard-CuBottom.gbr, 54PinTo60RibbonAdapterBoard-CuTop.gbr, 54PinTo60RibbonAdapterBoard-EdgeCuts.gbr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]
2025-10-30 Updated PCB:
    - Changed Pico pin assignment, so differential pairs can be tuned and Game Gear connections optimised if needed (code needs refreshing to match)
    - Changed PWM components to SMD versions, and moved to left side of board away from the Game Gear's oscillator
    - Moved 5V and GND connection points to left side with PWM components
    - Repositioned holes for the the FPC adapter board to align the connector for the LCD position
    - Added footprint for an FPC connector as alternative to an adapter board
    - HDMI differential pairs tuned to about 44.444mm length
    - Added level shifters to parse GG signals from 5v to 3.3v
    - Added diode to Pico's 3.3v output
    - Rounded board corners
    - Added LCSC par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
    [BOM-GG_LCD_DIY.csv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]
2025-10-30 Added WIP InstallationBoard kicad project
    [BOM-InstallationBoard.csv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]
2025-10-30 Added WIP InstallationFlex PCB
    [BOM-InstallationFlex.csv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]
2025-10-30 Added "gg_" prefix to game gear pin constant
    Updated pin assignments to match PCB
    Added usb streaming of framebuffer and a python script to view for testing purposes
    WIP - trying to fix lines missing from start of frame
    WIP - tweaking the PWM frequency
    [gg_viewer.py, main.c]
2025-11-09 Corrected pin assignments to be sequential.
    Added some pwm variables.
    Added pwm feedback logic to run on core1.
    Commented out brightness control for now, probably needs combining with the pwm feedback logic to regulate the pwm voltage target.
    Temporarily forced the GG output and disabled the SMS output.
    [main.c]
2025-11-09 Updated pin assignments on main PCB to match pico code using the correct sequential pins.
    54PinTo60RibbonAdapterBoard tweaked trace layout to reduce overall board size slightly.
    Added InstallationFlexWithSolderPoints for installing without a ribbon connector.
    [54PinTo60RibbonAdapterBoard-CuBottom.gbr, 54PinTo60RibbonAdapterBoard-CuTop.gbr, 54PinTo60RibbonAdapterBoard-EdgeCuts.gbr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]
2025-11-09 Added initial version of frame stl file
    [PICO GG LCD FRAME.stl]
2025-11-09 Update pin assignments in gg_capture.pio
    Added a wait_cycles to lcd_send.pio as it seemed a little quick
2025-11-11 Added wip LCDRibbonDevTest
    [LCDRibbonDevTest.kicad_pcb, LCDRibbonDevTest.kicad_sch, pcb.kicad_pcb]
2025-11-11 Corrected resistor values and part numbers.
    Tweaked board outline to avoid resistor on GG.
    Rerouted +3V3 around board.
    [BOM-GG_LCD_DIY.csv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]
2025-11-11 Fixed second frame buffer overlapping with the first.
    [main.c]
2025-11-14 index on vscode-import: 2af1a2f Corrected resistor values and part numbers.
    [main.c]
2025-11-14 Tweaked pio programs so waits are done with square bracket notation
2025-11-14 Increased text size on installation flex
    [InstallationFlexWithSolderPoints.kicad_pcb]
2025-11-16 Updated 54/60 Pin FPC connector footprint.
    [54PinTo60RibbonAdapterBoard.kicad_pcb, GG_LCD_DIY.kicad_pcb]
2025-11-27 Updated PicoDVI (libdvi) with audio support from ikjordan fork.
    Started adding code to process GG audio but need to reorder pins to free up ADC pins, or use a separate ADC module. Still very WIP.
    The audio-less HDMI works, but needs temporary work around to reverse bit order as the pins on the pcb are wrong way around.
    Added main.h to start adding any shared constant defines.
    Added constants to specify the pio instance and state machine to use for each program.
    Added a front horizontal porch pio program "front_h_porch" to avoid capturing some pixels.
    [dvi.c]
2025-11-27 Started updating PCB to support being rotated 180 degrees to allow LCD ribbon to be fed underneath instead of over the top.
    Switched pins of brightness/pwm feedback so they dont cross over each other.
    [GG_LCD_DIY.kicad_pcb, GG_LCD_DIY.kicad_sch]
2025-12-03 Added lcd_send_spi to serialise the frame data to 2 shift registers which connect to the lcd, allows 60fps 640x480 12bit RGB444.
    Pins assignments to be corrected.
    [main.c]
2025-12-03 Tweaked board outline.
    [GG_LCD_DIY.kicad_pcb]
2025-12-05 Higher res screen works well with 3 shift registers for 70-80fps, so overhead for other processing between frames, but requires a pin for each shift register serial in so 3 MOSI pins.
    This is with 4x horizontal and 3x vertical scaling for GG, with header and footer lines.
    2 shift registers works ok at about 60fps but seems to be pushing the registers response times.
    Disabled the DMA channels that discard lines, think at least 1 line was actual frame that was getting lost.
2025-12-05 Updated code with pio constants following previous merge.
    Fixed capture without the DMA channel skipping lines.
    [main.c, main.h]
2025-12-10 HDMI with audio working, but audio quality depends on audio source, but under 60fps as lcd_send_spi is now a single program on a single state machine but can be faster when run across 2.
    Pin assignments all unconfirmed for now.
2025-12-11 Started updating PCB and schematic, adding shift registers, audio lines, and changing to separate pwm module to save pins.
    [GG_LCD_DIY.kicad_pcb, GG_LCD_DIY.kicad_sch]
2025-12-14 Updated pins to match current prototype.
    Added SPI for an input shift register for buttons.
    Started adding a basic overlay.
2025-12-16 Restored framebuffer swapping for video outputs.
    Centered hdmi output, with 4x horizontal and 3x vertical scaling which matches the lcd output.
    Added title, fps counter, and button status to overlay, although it flickers on hdmi out as overlay is only drawn during the lcd output.
    [dvi.c, main.c, main.h]
2025-12-17 Mostly updated kicad project to match current prototype
    - Pick-And-Place SMT components moved to PCB backside
    - Hand solder components, i.e. ribbon connectors , stay on front side
    - Ribbon connectors for GG data and control inputs
    - Ribbon connector for "DVI" output connector
    - Shift registers for LCD
    - 3.3v buck circuit instead of using Pico circuit to help minimise ADC noise
    - 20v boost circuit instead of using Pico PWM to free up pins
    [GG_LCD_DIY.kicad_pcb, GG_LCD_DIY.kicad_sch]
2025-12-19 More PCB tweaks, added some bypass caps, changed some pin assignments to improve board layout
    [BOM-GG_LCD_DIY.csv, GG_LCD_DIY.kicad_pcb, GG_LCD_DIY.kicad_sch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]
2025-12-19 Added TestPoints to updated PCB for manual soldering install without a ribbon.
    [CPL-GG_LCD_DIY.csv, GG_LCD_DIY-CuBottom.gbr, GG_LCD_DIY-CuTop.gbr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]
2025-12-22 Added NewInstallationRibbon that unfolds across the motherboard with 2 ribbon connections on each side and solder points for all the game gear inputs and video data.
    Updated some pin assignments to help with layout of the installation ribbon, to reduce signals crossing over each other.
    [BOM-NewInstallationRibbon.csv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]
2025-12-23 Added LM358 op-amp for both audio channels.
    Updated ribbon connector pin assignments, text labels, and tweaked board outline.
    Gerbers updated for production.
    [BOM-GG_LCD_DIY.csv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]
2025-12-25 Corrected some component positions
    Updated lcd frame design
    [GG_LCD_DIY.kicad_pcb, PICO GG LCD FRAME 2.stl, PICO GG LCD FRAME.stl]
2026-01-11 PCB fixes for second prototype boards:
    Fixed DIR pin on transceiver/level shifter not being tied high.
    Fixed /SRCLR pin on shift registers not being tied high.
    Tied Pico VBUS to +5V so usb can power the board.
    Increased hole size on mounting points.
    [GG_LCD_DIY.kicad_pcb, GG_LCD_DIY.kicad_sch]
2026-01-25 Main PCB updated for third prototype boards. Most things moved around and rerouted. Also:
    - Audio circuit changed to use LMV321 op amp, with zero-ohm resistors as placeholders for tweaks.
    - Flex PCB Input connector changed to a single 24pin connection.
    - Video out changed to normal type-a instead of micro, and moved across board.
    - Shift registers changed to 5v with voltage dividers on data lines to lcd.
    - Diode footprints changed to smaller SOD-323.
    - Added diode and trace from Pico VBUS to +5v so the board will run from USB.
    -Testpoints changed 1mm.
    [BOM-GG_LCD_DIY.csv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]
2026-01-25 Flex PCB updated:
    - Use a single 24pin connection to the main board, pin out updated to match the main board.
    - Various layout tweaks to improve installation by reducing some of the slack.
    - Added rule areas around solder points to exclude copper fills to help align the solder points.
    - Added guide holes for the top row of cartridge connector pins, and tweaked the other guide holes to help with install.
    [Drill_PTH_Through.DRL, Drill_PTH_Through_Via.DRL, Gerber_BoardOutlineLayer.GKO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]
2026-01-25 Added 3d prints for the two different style micro video out connector boards.
    [PICO GG MICRO NOT HDMI UPSIDEDOWN 2.stl, PICO GG MICRO NOT HDMI UPSIDEDOWN.stl]
2026-01-28 Fixed hdmi lines having capacitors instead of resistors.
    [GG_LCD_DIY.kicad_pcb, GG_LCD_DIY.kicad_sch]
2026-02-08 Fixed voltage divider in audio ADC circuit.
    [GG_LCD_DIY.kicad_pcb, GG_LCD_DIY.kicad_sch]
2026-02-11 WIP commit of working audio capture, uses last 2 DMA channels, chained together for the audio ring buffer. Sounds good, could be amplified more.
2026-02-13 Fixed wrong GND pin on installation ribbon!
    [NewInstallationRibbon.kicad_pcb, NewInstallationRibbon.kicad_sch]
2026-02-26 Rearranged shift register RGB sequence to fix needing to left-shift the pixel data 20 bits.
    Moved "Video Out" connector for better clearance in the case.
    Changed some individual resistors for resistor arrays.
    [BOM-GG_LCD_DIY.csv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]
2026-02-26 PCB updated for 4th prototype.
    Tweaked board outline, added 3rd screw hole back.
    [BOM-GG_LCD_DIY.csv, BOM_GG_LCD_DIY_GG_LCD_DIY_2026-02-26.csv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]
2026-03-09 WIP tweaks for fixing the bit shifting required for the serial to parallel shift registers.
    [main.c]
2026-03-16 Updated hdmi pin assignments to match pcb.
    Removed bit shifting for the lcd shift registers as the pcb is now corrected.
    Tweaked frame capture to include some lines after vblank so the very first real line can be caught.
    Started removing waits for the gg pixel clock pin and use delay cycles instead as the timing is currently about 7 delays cycles per pixel when overlocked to 252mhz for libdvi.
    [dvi.c, main.c, main.h]
2026-03-17 Updated get_data pio program to use a clock divider to match the gg pixel clock, so it doesn't need a clock pin anymore and is synced to the hsync signal with the same 32.2mhz timing as the gg... ass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
    Started tidying code up, and trying to fix other vsync issues with both lcd and libdvi.
    [dvi.c, main.c, main.h]
2026-03-26 Tidied code and repository.
    Added header file for pin assignments.
    Added cmake options to .gitignore and removed cmakefiles folder
    Deleted old installation ribbon projects.
    Moved 3dprint files.
    Generated schema.
    [54PinTo60RibbonAdapterBoard-CuBottom.gbr, 54PinTo60RibbonAdapterBoard-CuTop.gbr, 54PinTo60RibbonAdapterBoard-EdgeCuts.gbr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]
2026-04-08 Switching between GG and SMS mode now works
2026-04-09 Updated readme with details of WL355608 prototype
